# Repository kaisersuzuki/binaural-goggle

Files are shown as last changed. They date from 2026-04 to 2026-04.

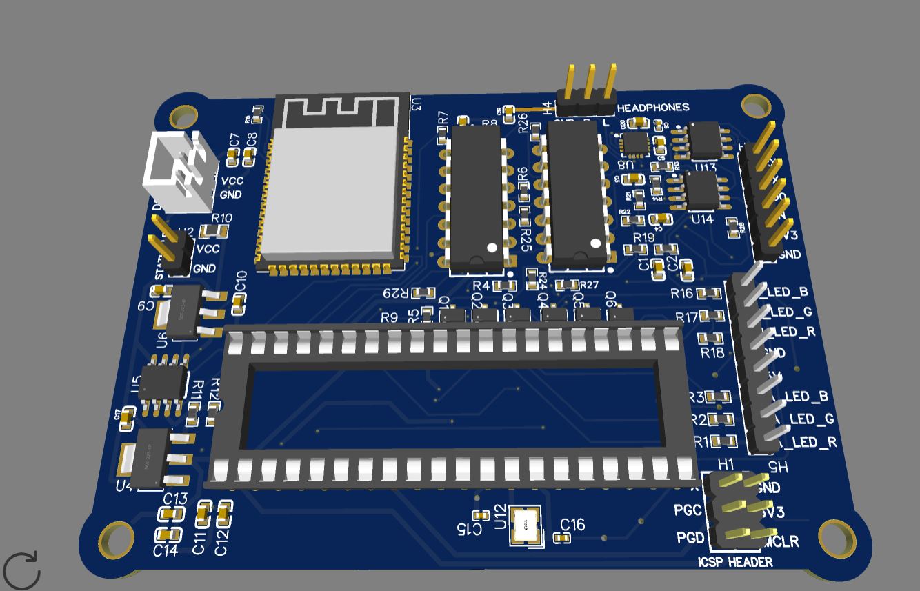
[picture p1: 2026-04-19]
hardware/pcb/images/1.JPG

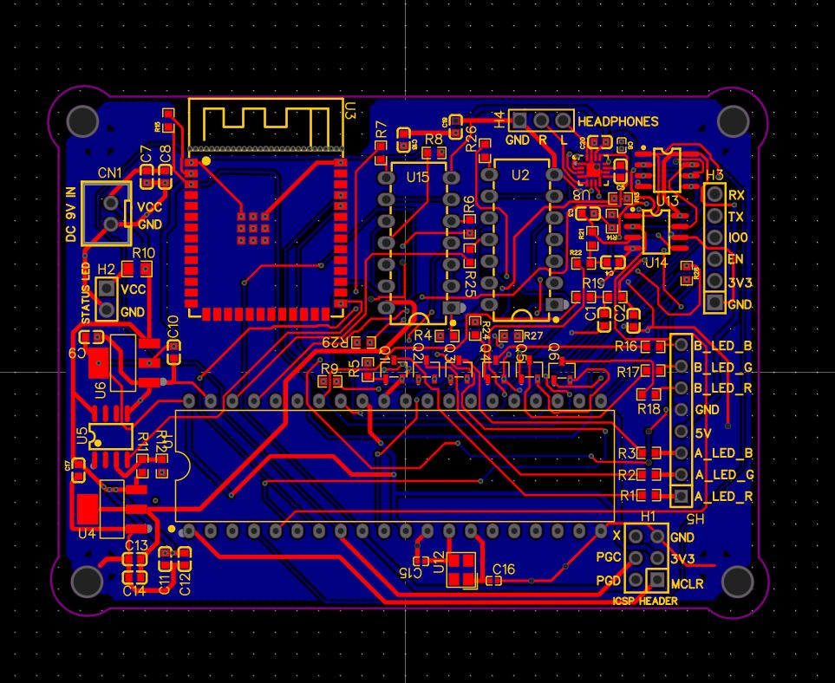
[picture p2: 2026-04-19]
hardware/pcb/images/2.JPG

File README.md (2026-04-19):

# Binaural Beat + RGB LED Goggle Controller

A DIY meditation device combining a dsPIC30F4013 microcontroller with an ESP32-WROOM-32E,
RGB LED arrays mounted in ski goggle frames, binaural beat audio output, and WiFi control
via an embedded ESP32 web server. Housed in a custom ASA FDM 3D-printed enclosure.

**License:** CC BY-NC 4.0 — personal/educational use only, not for commercial use.

---

## Hardware Overview

| Component | Part | Notes |
|---|---|---|
| Microcontroller | dsPIC30F4013-20I/P | PDIP-40, socketed, DigiKey |
| WiFi module | ESP32-WROOM-32E | SMD, JLCPCB assembled |
| Headphone amp | TPA6132A2 | WQFN-17, SMD |
| Digital pot (volume) | AD5220BRZ50 | SOIC-8, SPI, 64-step × 2 |
| 3.3V LDO | LD1117AG-3.3V | SO-8 |
| 5V LDO | AMS1117-5.0 | SOT-223 |
| Battery monitor | MAX8212ESA+T | SOIC-8 |
| LED driver | NTE74HC14 (74HC14) | Schmitt inverter × 2 ICs |
| LED transistor | 2N3904S | NPN × 6 |
| Crystal | 10MHz | HC-49S |
| LEDs | RGB common-cathode | 3× per eye, 2 eyes |
| Enclosure | Custom FDM ASA, JLC3DP | 99×79×51mm body + lid |
| PCB | 2-layer FR4, JLCPCB | 84.4×62.4mm, rounded corners |

### Panel Connectors
| Connector | Part | Location | Function |
|---|---|---|---|
| DC barrel jack | 5.5×2.1mm | Rear panel | 9V power input |
| Power switch | 12mm SPST latching toggle | Rear panel | Power on/off |
| GX16-8 | Female chassis socket | Front panel | Goggle cable |
| Headphone jack | Neutrik NJ3FP6C | Front panel | Stereo TRS output |
| Status LED | 5mm panel mount | Front panel | Power indicator |

---

## PCB Pin Assignments

### dsPIC30F4013 (U1)
| Pin | Function | Connected to |
|-----|---|---|
| 1 | MCLR | 10kΩ → 3.3V, ICSP |
| 6 (RB4) | Eye A — Red | HC14 → 2N3904 → LED |
| 7 (RB5) | Eye A — Green | HC14 → 2N3904 → LED |
| 8 (RB6/PGC) | Eye A — Blue | HC14 → 2N3904 → LED |
| 9 (RB7/PGD) | Eye B — Red | HC14 → 2N3904 → LED |
| 10 (RB8) | Eye B — Green | HC14 → 2N3904 → LED |
| 38 (RB9) | Eye B — Blue | HC14 → 2N3904 → LED |
| 37 (RB10) | TPA6132A2 EN | Amp enable (HIGH = on) |
| 4 (RB2) | AD5220 /CS | SPI chip select |
| 5 (RB3) | AD5220 U/D | SPI up/down |
| 24 (RF6/SCK1) | AD5220 CLK | SPI clock |
| 25 (RF3/SDO1) | AD5220 DI | SPI data |
| 27 (RF5/U2TX) | ESP32 RX | UART2 TX |
| 28 (RF4/U2RX) | ESP32 TX | UART2 RX |
| 33 (RD1/OC2) | PWM Right | Audio PWM right channel |
| 34 (RD0/OC1) | PWM Left | Audio PWM left channel |
| 13 (OSC1) | Crystal | 10MHz |
| 14 (OSC2) | Crystal | 10MHz |

> **Note:** RB6 and RB7 are shared with PGC/PGD (ICSP programming pins).
> LEDs will flash briefly during firmware programming — this is expected and harmless.

### ESP32-WROOM-32E (U7)
| GPIO | Function | Connected to |
|---|---|---|
| GPIO16 (RX2) | UART2 RX | dsPIC U2TX (RF5) |
| GPIO17 (TX2) | UART2 TX | dsPIC U2RX (RF4) |
| GPIO0 | Boot mode | Voltage divider on PCB |

### Connector Headers
| Ref | Pins | Function |
|-----|---|---|
| J1 / H1 | 2×3 (6-pin) | ICSP — dsPIC programming (PICkit 4) |
| J2 / H3 | 1×6 | ESP32 programming (GND/3V3/EN/IO0/TX0/RX0) |
| J3 / PS1 | GX16-8 | Goggle cable (A_R/A_G/A_B/B_R/B_G/B_B/5V/GND) |
| J4 / H4 | 1×3 | Headphone jack (GND/R/L → Neutrik NJ3FP6C) |
| J5 / H2 | 1×2 | Status LED (VCC/GND) |
| J6 / CN1 | 1×2 | 9V power input (VCC/GND from barrel jack) |
| J7 | — | UART debug (not populated) |

### GX16-8 Pin Map
| GX16-8 Pin | Signal |
|---|---|
| 1 | Eye A — Red |
| 2 | Eye A — Green |
| 3 | Eye A — Blue |
| 4 | Eye B — Red |
| 5 | Eye B — Green |
| 6 | Eye B — Blue |
| 7 | +5V |
| 8 | GND |

---

## Repository Structure

```
binaural-goggle/
├── firmware/
│   ├── dspic/
│   │   └── src/
│   │       └── dspic_firmware.c      # dsPIC30F4013 main firmware
│   └── esp32/
│       └── src/
│           └── main.cpp              # ESP32 WiFi + web server firmware
├── hardware/
│   ├── schematic/
│   │   ├── binaural_goggle_schematic.html     # Schematic rev 0.1 (original)
│   │   ├── Schematic_AUDIO-CONTROLLER_REV1.1.pdf  # Final schematic
│   │   └── images/
│   │       ├── schematic_rev0.1.png
│   │       └── schematic_rev1.1_*.png
│   ├── pcb/
│   │   ├── Gerber_AUDIO-CONTROLLER_2026-04-19.zip
│   │   ├── PCB_AUDIO-CONTROLLER_2026-04-19.json
│   │   ├── SCH_AUDIO-CONTROLLER_2026-04-19.json
│   │   └── images/
│   │       ├── pcb_top.jpg
│   │       ├── pcb_bottom.jpg
│   │       └── pcb_3d_*.jpg
│   └── bom/
│       └── BOM_AUDIO-CONTROLLER.csv
├── enclosure/
│   ├── enclosure_body_v8_FINAL.stl
│   ├── enclosure_lid_v8_FINAL.stl
│   └── insert_drawing_v7.pdf
└── docs/
    ├── README.md                     # This file
    ├── ARCHITECTURE.md
    ├── UART_PROTOCOL.md
    └── PROGRAMMING.md
```

---

## Firmware: dsPIC30F4013

### Build Environment
- MPLAB X IDE (latest)
- XC16 compiler
- PICkit 4 programmer

### Key Parameters
| Parameter | Value |
|---|---|
| Crystal | 10MHz |
| PLL | ×4 |
| Fcy | 20MHz |
| DDS sample rate | 8kHz (Timer1 ISR) |
| PWM frequency | ~256kHz (OC1/OC2) |
| UART2 baud rate | 9600 |
| Beat range | 0.5–40Hz |
| Carrier range | 50–500Hz |
| Volume steps | 0–63 (AD5220) |

### Beat Pattern (default)
| Phase | Frequency | Duration |
|---|---|---|
| Baseline | 4Hz (theta) | continuous |
| Spike | 8Hz | 40 seconds every ~8 min |
| Dip | 2Hz | 90 seconds every ~13 min |
| Ramp | smooth | 3 second transitions |

### UART Command Protocol
Commands are ASCII, newline-terminated, sent from ESP32 to dsPIC:

```
BEAT:<hz>           — set beat frequency (0.5–40.0)
CARRIER:<hz>        — set carrier frequency (50.0–500.0)
VOL:<0-63>          — set volume step
RGB_A:<r>,<g>,<b>   — set eye A color (0–255 each)
RGB_B:<r>,<g>,<b>   — set eye B color
RGB_AB:<r>,<g>,<b>  — set both eyes same color
STATUS              — returns current state string
RESET               — reset sequencer to baseline 4Hz
```

dsPIC responds with `OK:<cmd>` or `ERR:UNKNOWN`.

---

## Firmware: ESP32

### Build Environment
- VS Code + PlatformIO
- Arduino framework for ESP32

### WiFi
| Setting | Value |
|---|---|
| Mode | AP (Access Point) |
| SSID | BinauralGoggle |
| Password | meditate123 |
| Web UI | http://192.168.4.1 |
| OTA hostname | binaural-goggle |
| OTA password | goggle-ota |

### First Flash (via J2 programming header)
1. Connect FTDI/CP2102 adapter to J2 (GND/3V3/EN/IO0/TX0/RX0)
2. Hold IO0 low during power-up to enter boot mode
3. Flash via PlatformIO: `pio run --target upload`
4. Subsequent updates via OTA

### Production Flash Note
Once `Serial` (USB debug) is no longer needed, the firmware uses `Serial2` only
(GPIO16/17) for dsPIC communication. USB serial is kept for debug output.

---

## Power

- Input: 9V DC wall adapter, 5.5×2.1mm center-positive, 1A minimum
- Panel switch (rear): SPST latching 12mm toggle, in series with 9V input
- 3.3V rail: LD1117AG-3.3V LDO (logic, dsPIC, ESP32)
- 5V rail: AMS1117-5.0 LDO (LEDs, headphone amp)
- No battery, no protection diode required

---

## Programming the dsPIC

Connect PICkit 4 to J1 (ICSP header, 2×3 male):

| Pin | Signal |
|-----|---|
| 1 | MCLR |
| 2 | VDD (3.3V) |
| 3 | VSS (GND) |
| 4 | PGD (RB7) |
| 5 | PGC (RB6) |
| 6 | NC |

> LEDs may flash briefly during programming due to PGC/PGD sharing RB6/RB7.

---

## 3D-Printed Enclosure

Printed by JLC3DP in ASA black FDM.

| Part | File | Dimensions |
|---|---|---|
| Body | enclosure_body_v8_FINAL.stl | 99×79×39.5mm |
| Lid | enclosure_lid_v8_FINAL.stl | 99×79×11.5mm |
| Insert drawing | insert_drawing_v7.pdf | 4× M3×4×5 at (±38, ±27mm) |

### Panel Hole Positions (Z=24mm from bottom)
| Hole | Diameter | X position | Panel |
|---|---|---|---|
| GX16-8 | 16.2mm | X=−20 | Front |
| TRS headphone | 9.5mm | X=+22 | Front |
| Status LED | 5.2mm | X=0 | Front |
| DC barrel jack | 8.2mm | X=+20 | Rear |
| Power switch | 12.2mm | X=−20 | Rear |

---

## Hardware Still Needed (to order)

- [ ] Neutrik NJ3FP6C — 1/4" stereo TRS panel jack
- [ ] GX16-8 female chassis socket + male cable plug
- [ ] 12mm SPST latching toggle switch
- [ ] 5.5×2.1mm DC barrel jack (panel mount)
- [ ] 9V DC wall adapter, 1A, center-positive
- [ ] PICkit 4 programmer
- [ ] dsPIC30F4013-20I/P (PDIP-40, DigiKey)
- [ ] USB-UART adapter (FTDI or CP2102) for initial ESP32 flash

---

*Brad Beidler · 2026 · CC BY-NC 4.0*

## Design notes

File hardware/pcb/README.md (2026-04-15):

# PCB Files

> **Status:** Layout in progress with JLCPCB Layout Service (Atan). Gerbers will be added here once received and approved.

## What goes here

Once the PCB design is finalized, this folder should contain:

| Folder | Contents |
|---|---|
| `gerbers/` | Production Gerber files (RS-274X) — what JLCPCB needs to manufacture |
| `bom/` | Bill of materials (CSV with LCSC part numbers for each component) |
| `cpl/` | Component Placement List (CSV with X/Y/rotation for pick-and-place) |

Plus the EasyEDA Pro source files:

- `binaural_goggle.epro` — EasyEDA Pro project file
- `schematic.json` — schematic source
- `pcb.json` — PCB layout source

## Specs

- 82 × 60 mm
- 2-layer, 1.6mm thick, 1oz copper
- ENIG finish (or HASL for cheaper)
- 4× M3 mounting holes at corners (3.5mm clearance, non-plated)
- Top side components only

## Key components

- **U1** dsPIC30F4013 — PDIP-40, socketed (DIP socket on PCB, chip inserted by user, not assembled by JLCPCB)
- **U2** ESP32-WROOM-32E — SMD module, JLCPCB assembled
- **U3** TPA6132A2 (or NTE941M) — headphone amp
- **U4** AD5220 — SPI digital pot
- **U5/U6** MAX603 ×2 — 3.3V and 5V LDOs
- **U7/U8** NTE74HC14 ×2 — Schmitt inverters for LED drivers
- 6× 2N3904 — RGB LED drivers
- All passives 0603 SMD

## Programming headers

Two headers must be exposed on the board:

1. **J1 — dsPIC ICSP**: 2×3 pin, 2.54mm. Pinout: MCLR / VDD / VSS / PGD / PGC / NC
2. **JESP — ESP32 programming**: 1×6 pin, 2.54mm. Pinout: GND / 3V3 / EN / IO0 / TX0 / RX0
   Plus BOOT and RESET momentary pushbuttons (or auto-reset transistor pair)

See `docs/programming.md` for use.

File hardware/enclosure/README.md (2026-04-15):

# Enclosure

3D-printed ASA case for the controller PCB. Currently at **v7** — pressure-fit lid, no lid screws.

## Files

| File | Purpose |
|---|---|
| `stl/enclosure_body_v7.stl` | Main body — 99 × 79 × 39.5 mm, open top, internal PCB standoffs |
| `stl/enclosure_lid_v7.stl` | Press-fit lid — 99 × 79 × 11.5 mm |
| `drawings/insert_drawing_v7.pdf` | Heat-set insert location drawing for JLC3DP order |

## Specs

- Material: **ASA**, black
- Process: **FDM** (JLC3DP)
- Surface finish: **yes** (smoother outer face)
- Threaded inserts: **4× M3 × 4mm OD × 5mm long**, all in PCB standoffs at (±38, ±27)
- Lid: pressure-fit, no inserts, no screws
- Mounting: PCB attaches to body via 4× M3 cap-head screws into the heat-set inserts

## Ordering from JLC3DP

1. Upload `enclosure_body_v7.stl` and `enclosure_lid_v7.stl`
2. For the body only, select:
   - Material: ASA
   - Color: Black
   - Surface finish: Yes
   - Threaded insert: M3 × 4 × 5, **quantity 4**
   - Upload `insert_drawing_v7.pdf` for insert locations
3. For the lid: same material/color/finish, no inserts

Cost: ~$25–35 per set. Lead time ~5–7 business days.

## SCAD source (TODO)

The `scad/` folder is a placeholder. Brad has the working SCAD source locally — drop `enclosure_v7.scad` here when convenient so the parametric source lives in version control alongside the STLs.

## History

- **v1–v6**: iterations during early development (not in repo)
- **v7** (current): pressure-fit redesign, removed all 4 lid bosses, 4 PCB inserts only

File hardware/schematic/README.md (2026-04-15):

# Schematic

| File | Description |
|---|---|
| `binaural_goggle_schematic_rev01.html` | Rev 0.1 — single-color red LEDs, no ESP32 |
| `binaural_goggle_schematic_rev02.png` | Rev 0.2 — adds ESP32, RGB LEDs, UART link, PDIP-40 dsPIC |

The HTML version is interactive (open in any browser). The PNG is the current revision and what's being implemented.

## Source files (TODO)

The EasyEDA Pro project source (`.epro`, `.json`) belongs in `../pcb/` and will be added once the layout service finalizes the design.

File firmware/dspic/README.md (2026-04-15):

# dsPIC30F4013 Firmware

The audio + LED engine. Generates binaural beats via DDS, drives RGB LEDs via soft-PWM, takes commands from the ESP32 over UART1.

## Toolchain

- **MPLAB X IDE** (free from microchip.com)
- **XC16 compiler** v2.x or later (free)
- **PICkit 4** programmer (~$50, DigiKey)

## Building

1. Open MPLAB X IDE → **File → New Project → Microchip Embedded → Standalone Project**
2. Family: **16-bit DSCs (dsPIC30)**, Device: **dsPIC30F4013**
3. Tool: **PICkit 4**, Compiler: **XC16**
4. Project name: `binaural_goggle_dspic`
5. Right-click *Source Files* → Add Existing Item → select `src/dspic_firmware.c`
6. **Build** (hammer icon)

## Flashing

1. Connect PICkit 4 to your Mac via USB
2. Connect PICkit 4 cable to PCB **J1** (5-pin ICSP header)
3. Pin orientation on J1: MCLR / VDD / VSS / PGD / PGC (pin 1 marked)
4. In MPLAB X click the **Make and Program Device** icon (downward arrow)
5. Watch the output pane — should see "Programming complete"

## Configuration

Edit constants near the top of `dspic_firmware.c`:

```c
#define SAMPLE_RATE         8000U     // DDS interrupt rate
#define DEFAULT_CARRIER_HZ  128       // Initial carrier
#define DEFAULT_BEAT_HZ     4.0f      // Initial beat
```

The runtime command interface (over UART1 from the ESP32) lets you change these without reflashing — see [`docs/uart_protocol.md`](../../docs/uart_protocol.md).

## Pin map

See header comment block in `src/dspic_firmware.c` for the full pin assignments. Summary:

| Pin | Function |
|---|---|
| RD0 (OC1) | Left audio PWM |
| RD1 (OC2) | Right audio PWM |
| RF6/RF7 + RB2/RB3 | SPI to AD5220 volume pot |
| RF2/RF3 | UART1 to ESP32 |
| RG2/3/4 | Left eye R/G/B LEDs |
| RG6/7/8 | Right eye R/G/B LEDs |
| AN0 | Battery voltage divider |

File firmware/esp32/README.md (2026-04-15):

# ESP32 Firmware

WiFi controller and web UI host. Receives commands from a browser over WiFi, translates them to UART ASCII commands for the dsPIC.

> **Status:** Smoke-test foundation only. Verified working end-to-end on ESP32 DevKitC (April 2026). Production version will add full command set, OTA updates, SPIFFS-served UI, and STA mode fallback.

## Toolchain

- **VS Code** with the **PlatformIO IDE** extension
- **CH340 USB-UART driver** (Mac): `brew install --cask wch-ch34x-usb-serial-driver`

## Building & flashing (during development)

1. Open this folder (`firmware/esp32/`) in VS Code with PlatformIO installed
2. Plug in the ESP32 DevKitC via USB
3. Click the **→** (Upload) icon in the bottom blue status bar
4. Click the **🔌** (Serial Monitor) icon to watch logs

## Flashing the final PCB (one-time)

The production PCB exposes a 6-pin programming header with `GND / 3V3 / EN / IO0 / TX0 / RX0`. To flash the initial firmware:

1. Connect a USB-UART adapter (FTDI or CP2102) to the header
2. Hold BOOT, tap RESET, release BOOT to enter download mode
3. `pio run --target upload` (or use the upload arrow in VS Code)
4. After this first flash, all subsequent updates happen via WiFi (OTA) — see below

## Using the web UI

1. After flashing, the ESP32 creates a WiFi network: **BinauralGoggle** (password: `meditate123`)
2. Connect from any phone/laptop
3. Browse to `http://192.168.4.1`
4. Adjust sliders, hit APPLY
5. Watch the serial monitor — you'll see the UART command that would be sent to the dsPIC

## Architecture

```
[Browser] ─HTTP─→ [ESP32 web server] ─UART2─→ [dsPIC30F4013]
              ←─events─                ←──────
```

- **Web server:** ESPAsyncWebServer on port 80
- **UI:** Single-page HTML/CSS/JS (currently inline, will move to SPIFFS)
- **UART bridge:** Translates JSON/form params to ASCII commands per [UART protocol](../../docs/uart_protocol.md)
- **OTA:** ArduinoOTA library, firmware updates via WiFi after initial flash

## Pin map (final PCB)

| ESP32 GPIO | Function |
|---|---|
| 1 (TX0)  | Programming header — initial flash only |
| 3 (RX0)  | Programming header — initial flash only |
| 16 (RX2) | UART2 from dsPIC TX (RF3) |
| 17 (TX2) | UART2 to dsPIC RX (RF2) |
| EN | Reset (boot button) |
| 0 | Boot mode select (boot button) |

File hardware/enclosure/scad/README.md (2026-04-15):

# OpenSCAD Source

Place `enclosure_v7.scad` here when ready.

The STL files in `../stl/` were exported from this source. Keeping the SCAD here in version control means future revisions can be parametric edits rather than starting from scratch.

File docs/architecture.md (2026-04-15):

# System Architecture

## Block diagram

```
┌─────────────────────────────────────────────────────────────────────┐
│                      BINAURAL GOGGLE CONTROLLER                     │
└─────────────────────────────────────────────────────────────────────┘

        9V battery
            │
        ┌───┴────┐
        │ MAX603 │── 3.3V ──┬─→ dsPIC VDD/AVDD
        │  LDO   │          ├─→ ESP32 3V3
        └────────┘          └─→ AD5220 / HC14 logic
            │
        ┌───┴────┐
        │ MAX603 │── 5.0V ──┬─→ NTE941M op-amp VCC
        │ (SET)  │          └─→ RGB LED supply
        └────────┘

  ┌─────────────────┐   WiFi    ┌──────────────────┐
  │  Phone/Laptop   │◄─────────►│  ESP32-WROOM-32E │
  │  (web browser)  │           │  (web server)    │
  └─────────────────┘           └────────┬─────────┘
                                         │ UART2 @ 115200
                                         │
                                ┌────────▼─────────┐
                                │  dsPIC30F4013    │
                                │  (PDIP-40)       │
                                │                  │
                                │  • DDS @ 8kHz    │
                                │  • Beat seq      │
                                │  • Noise gen     │
                                │  • SoftPWM LEDs  │
                                └──┬──────┬───┬────┘
                                   │      │   │
            ┌──── PWM ─────────────┘      │   └─── 6× GPIO ───┐
            │                             │                    │
            ▼                             ▼                    ▼
   ┌─────────────────┐         ┌─────────────────┐    ┌──────────────┐
   │  RC LPF (×2)    │         │  AD5220 SPI pot │    │  HC14 + 2N3904│
   │  Fc≈1.6kHz      │         │  (master vol)   │    │  RGB drivers  │
   └────────┬────────┘         └────────┬────────┘    └──────┬───────┘
            │                           │                    │
            ▼                           │                    ▼
   ┌─────────────────┐                  │           ┌──────────────┐
   │  NTE941M unity  │◄─────────────────┘           │  RGB LEDs    │
   │  buffers (×2)   │                              │  (in goggles)│
   └────────┬────────┘                              └──────────────┘
            │
            ▼
   ┌─────────────────┐
   │  3.5mm jack     │
   │  → headphones   │
   └─────────────────┘
```

## Why two MCUs

The dsPIC handles all hard-real-time work — running a DDS oscillator at 8 kHz with sample-accurate phase, generating noise, and managing LED PWM all from interrupts. Adding WiFi to that chip would either require a heavier processor or constant priority juggling.

The ESP32 handles only soft-real-time work: receive a web request, parse it, send an ASCII line over UART. It can take its time without affecting audio quality.

This separation also means the audio engine keeps running cleanly even if WiFi drops, the user's phone disconnects, or the ESP32 is OTA-updating itself.

## Programming workflow

| Component | First flash | Updates |
|---|---|---|
| dsPIC30F4013 | PICkit 4 + MPLAB X via J1 ICSP header | PICkit 4 (rare — firmware is stable) |
| ESP32-WROOM-32E | USB-UART adapter via 6-pin programming header | OTA over WiFi via web UI |

## Power

- **9V battery** (or DC jack) → switch → MAX603 ×2 → 3.3V and 5V rails
- **MAX8212** monitors battery voltage and signals dsPIC AN0 when low
- All bypass caps per datasheet

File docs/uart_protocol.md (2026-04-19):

# UART Protocol — ESP32 ↔ dsPIC30F4013

## Physical Layer

| Parameter | Value |
|---|---|
| Baud rate | 9600 |
| Format | 8N1 |
| ESP32 pin (TX) | GPIO17 (Serial2 TX) |
| ESP32 pin (RX) | GPIO16 (Serial2 RX) |
| dsPIC pin (RX) | RF4 / U2RX |
| dsPIC pin (TX) | RF5 / U2TX |
| Logic level | 3.3V (both devices) |

## Message Format

All messages are ASCII, newline (`\n`) terminated.
ESP32 sends commands; dsPIC responds.

## Commands (ESP32 → dsPIC)

| Command | Example | Description |
|---|---|---|
| `BEAT:<hz>` | `BEAT:4.0` | Set beat frequency (0.5–40.0 Hz) |
| `CARRIER:<hz>` | `CARRIER:200.0` | Set carrier frequency (50.0–500.0 Hz) |
| `VOL:<0-63>` | `VOL:32` | Set volume (AD5220 step position) |
| `RGB_A:<r>,<g>,<b>` | `RGB_A:255,0,0` | Set eye A color (0–255 each channel) |
| `RGB_B:<r>,<g>,<b>` | `RGB_B:0,0,255` | Set eye B color |
| `RGB_AB:<r>,<g>,<b>` | `RGB_AB:128,0,128` | Set both eyes same color |
| `STATUS` | `STATUS` | Request current state |
| `RESET` | `RESET` | Reset sequencer to 4Hz baseline |

## Responses (dsPIC → ESP32)

| Response | Meaning |
|---|---|
| `OK:BEAT` | Beat frequency accepted |
| `OK:CARRIER` | Carrier frequency accepted |
| `OK:VOL` | Volume set |
| `OK:RGB_A` | Eye A color set |
| `OK:RGB_B` | Eye B color set |
| `OK:RGB_AB` | Both eyes set |
| `OK:RESET` | Sequencer reset |
| `BEAT:x.x CARRIER:x.x VOL:xx` | Status response |
| `ERR:UNKNOWN` | Unrecognized command |
| `READY:BINAURAL_GOGGLE_V2` | Boot message (sent once on power-up) |

## Timing Notes

- dsPIC responds within ~1ms for most commands
- Volume changes (`VOL:`) take longer if stepping many positions (64 steps max = ~5ms)
- ESP32 waits up to 200ms for a response before returning "timeout" to the web UI
- STATUS response is always sent within 5ms

## Beat Frequency Ranges

| Range | Brainwave | Effect |
|---|---|---|
| 0.5–4 Hz | Delta | Deep sleep |
| 4–8 Hz | Theta | Meditation, drowsiness |
| 8–14 Hz | Alpha | Relaxed focus |
| 14–30 Hz | Beta | Active thinking |

Default session pattern:
- **4Hz theta** baseline
- **8Hz spike** every ~8 minutes (40 second duration)
- **2Hz dip** every ~13 minutes (90 second duration)
- All transitions ramp over 3 seconds

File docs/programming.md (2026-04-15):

# Programming Guide

How to flash firmware on both MCUs.

## Required tools

- **PICkit 4** programmer for the dsPIC (~$50 from DigiKey/Microchip)
- **MPLAB X IDE** + **XC16 compiler** for dsPIC firmware (free)
- **VS Code** + **PlatformIO** for ESP32 firmware (free)
- **CH340/CP2102 USB-UART adapter** for initial ESP32 flash (~$5)
- **CH340 driver** (Mac): `brew install --cask wch-ch34x-usb-serial-driver`

## Order of operations

1. Insert the dsPIC30F4013 into its PDIP-40 DIP socket on the assembled PCB
2. Flash the dsPIC via the J1 ICSP header
3. Flash the ESP32 via the 6-pin programming header
4. From here on, ESP32 firmware updates happen over WiFi (OTA)

## Flashing the dsPIC

1. Open `firmware/dspic/src/dspic_firmware.c` in MPLAB X (create a new project targeting **dsPIC30F4013** with **XC16** compiler)
2. Connect PICkit 4 → Mac via USB
3. Connect PICkit 4 → PCB **J1** (5-pin ICSP header). Pin 1 is marked on the board
4. Hit **Make and Program Device** (downward arrow icon)
5. Watch the output pane for "Programming complete"

If you get a "device not detected" error, check the J1 connector orientation and that the dsPIC has both VDD (3.3V) and VSS (GND) connected.

## Flashing the ESP32 (initial)

1. Connect USB-UART adapter to the 6-pin programming header on the PCB:
   - Adapter GND  → Header GND
   - Adapter 3V3  → Header 3V3 (or leave disconnected if board is powered via main supply)
   - Adapter TX   → Header RX0
   - Adapter RX   → Header TX0
   - Adapter DTR  → Header EN  (optional, for auto-reset)
   - Adapter RTS  → Header IO0 (optional, for auto-boot)
2. Hold **BOOT** button on PCB, tap **RESET**, release **BOOT**
3. In `firmware/esp32/`: `pio run --target upload`
4. After upload, tap **RESET** to start running

## Flashing the ESP32 (OTA, after first flash)

1. Connect to the WiFi network the ESP32 is on (either AP mode or your home network)
2. In your browser, go to the device's address (default: `http://192.168.4.1/update`)
3. Upload the new `firmware.bin` (built by `pio run`)
4. Device reboots automatically when complete

OTA is the normal update path — you should rarely need the wired programming header after the initial flash.

## Troubleshooting

| Symptom | Likely cause |
|---|---|
| PICkit 4 not detected | USB cable issue, or PICkit 4 needs a firmware update via MPLAB X |
| `device ID mismatch` | Wrong device selected in MPLAB X project — must be exactly dsPIC30F4013 |
| ESP32 upload "Connecting..." hangs | BOOT/RESET sequence wrong, or auto-reset wiring missing |
| Garbled serial output | Baud rate mismatch — check both ends are 115200 |
| WiFi network doesn't appear | Check `WiFi.softAP()` succeeded in serial logs |
| OTA upload fails | Check device IP, ensure same network, firewall blocking port 3232 |

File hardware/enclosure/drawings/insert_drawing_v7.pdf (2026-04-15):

## BINAURAL GOGGLE CONTROLLER — ENCLOSURE BODY v7

Heat-Set Insert Locations | M3 x 4mm OD x 5mm long | 4 inserts total
Brad Beidler | 2026 | JLC3DP ASA Black FDM | Pressure-fit lid (no lid inserts)

### TOP VIEW (looking down into open top of body)

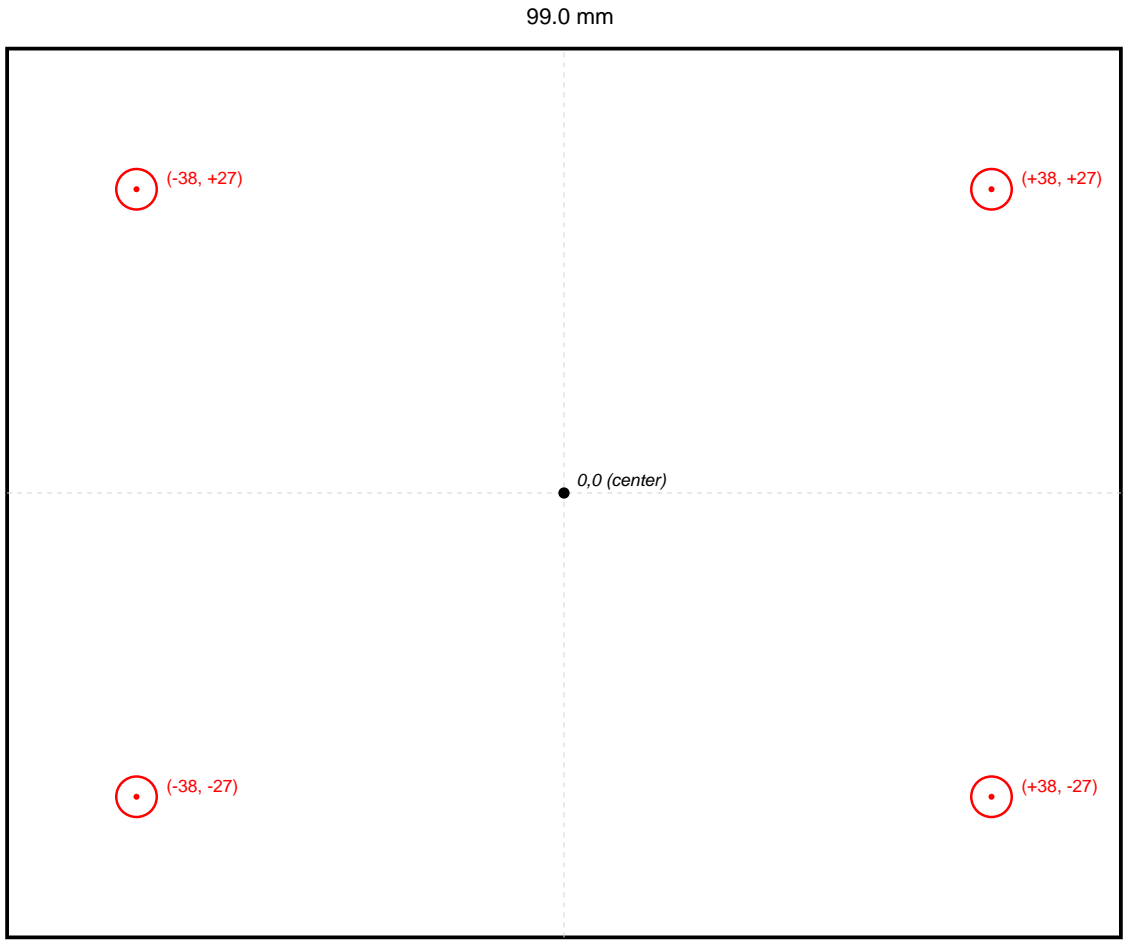
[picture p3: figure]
(+38, +27) 0,0 (center)

79.0 mm

LEGEND:
PCB standoff inserts (4 total) — at (±38, ±27)mm — short interior columns, hole faces UP

INSERT SPECIFICATION:

Insert type: | Brass heat-set, M3 x 4mm OD x 5mm long
JLC3DP catalog spec: | M3 x 4 x 5
Hole diameter: | 3.6 mm
Hole depth: | 7.0 mm
Total quantity: | 4 inserts
Orientation: | All 4 holes open to TOP face of body

NOTES:

1. All 4 insert holes open to the TOP face of the enclosure body (open side facing up).
2. PCB standoffs are short interior columns (~10mm tall) — accept inserts for M3 screws holding the PCB.
3. Lid is PRESSURE-FIT — no screws, no lid bosses, no lid inserts required.
4. Body external dimensions: 99 x 79 x 39.5 mm. Lid: 99 x 79 x 11.5 mm.
5. Material: ASA, black, FDM. Surface finish: yes.
File: enclosure_body_v7.stl | Drawing rev: v7-INS-01 | For JLC3DP threaded insert installation | Page 1 of 1

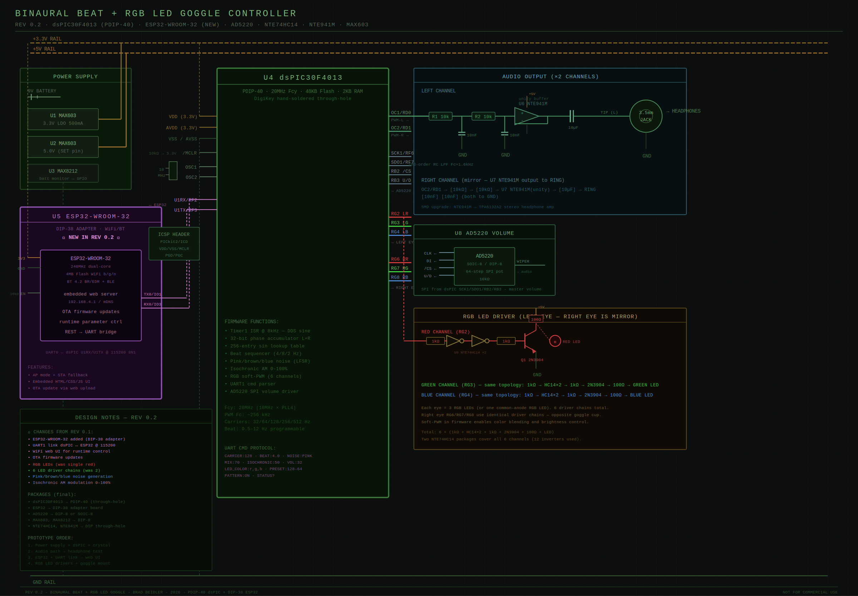
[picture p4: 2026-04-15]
hardware/schematic/binaural_goggle_schematic_rev02.png

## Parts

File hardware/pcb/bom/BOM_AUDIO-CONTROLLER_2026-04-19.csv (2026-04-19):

ID | Name | Designator | Footprint | Quantity | Manufacturer Part | Manufacturer | Supplier | Supplier Part | Price
1 | GX16-8 | H5 | HDR-TH_8P-P2.54-V-M | 1 | B-2100S08P-A110 | Ckmtw(灿科盟) | LCSC | C124381 | 0.08
2 | 10kΩ | R15,R13,R14,R19,R20,R21,R22 | R0603 | 7 | 0603WAF1002T5E | UNI-ROYAL(厚声) | LCSC | C25804 | 0.001
3 | ESP32-S3-WROOM-1(N8R8) | U3 | WIRELM-SMD_ESP32-S3-WROOM-1 | 1 | ESP32-S3-WROOM-1-N8R8 | ESPRESSIF(乐鑫) | LCSC | C2913201 | 5.043
4 | DC IN | CN1 | CONN-TH_2P-P2.50-XH2.54-2P | 1 | SH-XH2.54-2P | 深海电子 | LCSC | C53261323 | 0.004
5 | 10nF | C1,C2,C3,C4 | C0603 | 4 | 0603B103K500NT | FH(风华) | LCSC | C57112 | 0.003
6 | 1uF | C5 | C0603 | 1 | CGA3E1X7R1V105KT000S | TDK | LCSC | C36828386 | 0.091
7 | 100nF | C7,C10,C11,C14,C17,C18,C19,C20 | C0603 | 8 | CC0603KRX7R9BB104 | YAGEO(国巨) | LCSC | C14663 | 0.003
8 | 10uF | C8,C9,C12,C13 | C0603 | 4 | CL10A106KP8NNNC | SAMSUNG(三星) | LCSC | C19702 | 0.008
9 | 2.2uF | C6 | C0402 | 1 | GRM155D71C225ME11D | muRata(村田) | LCSC | C668350 | 0.07
10 | 22pF | C15,C16 | C0402 | 2 | CQ0402JRNPO9BN220 | YAGEO(国巨) | LCSC | C577409 | 0.008
11 | ICSP HEADER | H1 | HDR-TH_6P-P2.54-V-F-R2-C3-S2.54 | 1 | Female header/2.54mm2x3 Female header | ReliaPro | LCSC | C47552
12 | STATUS LED | H2 | HDR-TH_2P-P2.54-V-M-1 | 1 | 826629-2 | TE Connectivity(泰科电子) | LCSC | C86471 | 0.415
13 | ESP32 | H3 | HDR-TH_6P-P2.54-V-M-1 | 1 | 2.54-1x6P直针 | BOOMELE(博穆精密) | LCSC | C37208 | 0.042
14 | NJ3FP6C | H4 | HDR-TH_3P-P2.54-V-M-1 | 1 | 2.54-1*3P针 | BOOMELE(博穆精密) | LCSC | C49257 | 0.021
15 | 2N3904S-HXY | Q1,Q2,Q3,Q4,Q5,Q6 | SOT-23-3_L3.0-W1.7-P0.95-LS2.9-BR | 6 | 2N3904S-HXY | HXY MOSFET(华轩阳电子) | LCSC | C46682376 | 0.01
16 | 100R | R1,R2,R3,R16,R17,R18 | R0603 | 6 | 0603WAF1204T5E (SMT业务专用) | null | LCSC | C22766
17 | 1kΩ | R4,R5,R6,R7,R8,R9,R24,R25,R26,R27,R28,R29 | R0603 | 12 | 0603WAF1001T5E | UNI-ROYAL(厚声) | LCSC | C21190 | 0.002
18 | 100kΩ | R11 | R0603 | 1 | 0603WAF1003T5E | UNI-ROYAL(厚声) | LCSC | C25803 | 0.002
19 | 33kΩ | R12 | R0603 | 1 | 0603WAD3302T5E | UNI-ROYAL(厚声) | LCSC | C407593 | 0.005
20 | 1.2kΩ | R10 | R0805 | 1 | FRC0805F1201TS | FOJAN(富捷) | LCSC | C2933293 | 0.002
21 | DSPIC30F4013-20E/P | U1 | PDIP-40_DSPIC30F3014-30IP | 1 | dsPIC30F4013-20E/P | MICROCHIP(美国微芯) | LCSC | C613576 | 18.781
22 | 74HC14 | U2,U15 | DIP-14_L19.1-W6.4-P2.54-LS7.6-BL | 2 | 74HC14 | I-CORE(中微爱芯) | LCSC | C2974582 | 0.193
23 | AMS1117-5.0 | U4 | SOT-223_L6.5-W3.5-P2.30-LS7.0-BR | 1 | AMS1117-5.0 | AMS | LCSC | C6187 | 0.231
24 | MAX8212ESA+T | U5 | SOIC-8_L5.0-W4.0-P1.27-LS6.1-BL | 1 | MAX8212ESA+T | ADI(亚德诺)/MAXIM(美信) | LCSC | C2070193 | 5.251
25 | LD1117AG-3.3V-A | U6 | SOT-223-3_L6.5-W3.4-P2.30-LS7.0-BR | 1 | LD1117AG-3.3V-A | UTC(友顺) | LCSC | C474404 | 0.075
26 | TPA6132A2RTER | U8 | WQFN-16_L3.0-W3.0-P0.50-TL-EP1.6 | 1 | TPA6132A2RTER | TI(德州仪器) | LCSC | C69901 | 1.269
27 | 10MHz | U12 | CRYSTAL-SMD_4P-L3.2-W2.5-BL | 1 | XC32M4-10.000-F10LLDT | HCI(杭晶) | LCSC | C2848219 | 0.149
28 | AD5220BRZ50 | U13,U14 | SOIC-8_L4.9-W3.9-P1.27-LS6.2-BL | 2 | AD5220BRZ50 | ADI(亚德诺) | LCSC | C649362 | 5.701

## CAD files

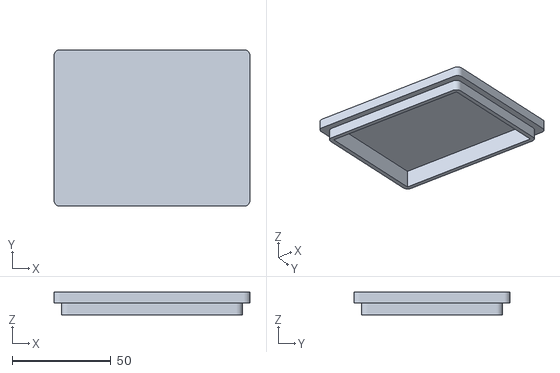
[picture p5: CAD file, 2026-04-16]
hardware/enclosure/stl/enclosure_lid_v8_FINAL.stl
99.0 x 79.0 x 11.5

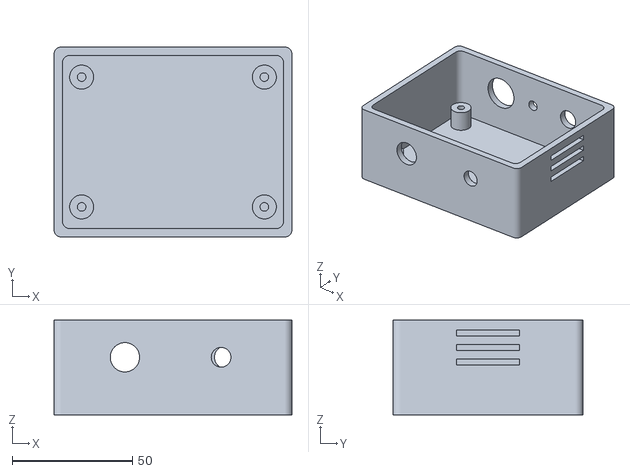
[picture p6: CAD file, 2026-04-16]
hardware/enclosure/stl/enclosure_body_v8_FINAL.stl
99.0 x 79.0 x 39.5

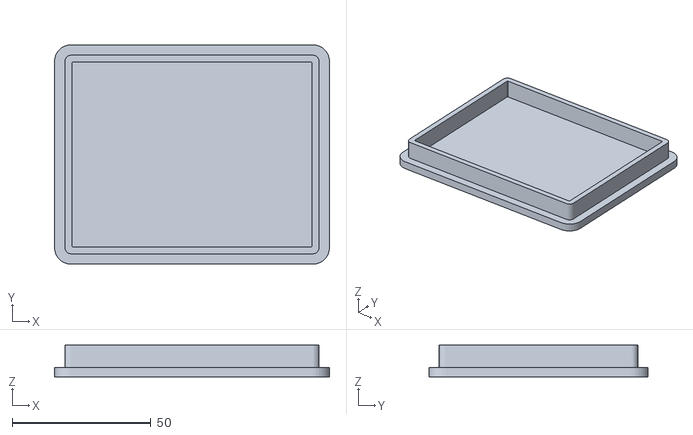
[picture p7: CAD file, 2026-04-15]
hardware/enclosure/stl/enclosure_lid_v7.stl
99.0 x 79.0 x 11.5

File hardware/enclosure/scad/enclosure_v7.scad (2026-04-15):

// ============================================================
// Binaural Goggle Controller — Enclosure Rev 3
// Brad Beidler · 2026
// ============================================================
// FIX: cavity subtraction PRESERVES standoff and boss positions
// by subtracting (cavity - standoffs) rather than cavity alone.
// Single monolithic difference — valid manifold, no multi-shell.
//
// PCB STANDOFFS:  (±38, ±27)  h=10mm  PCB drops straight in
// LID BOSSES:     (±43, ±32)  h=30mm  fused to wall corners
// ============================================================

$fn = 48;
RENDER_PART = "body";  // "body" | "lid" | "both"

// ── Core dimensions ──────────────────────────────────────────
INT_W = 92;  INT_L = 72;  INT_H = 30;
WALL  = 3.5;
EXT_W = INT_W + WALL*2;
EXT_L = INT_L + WALL*2;
EXT_H = INT_H + WALL;
OUTER_R = 6.0;  INNER_R = OUTER_R - WALL;

// ── Lid ──────────────────────────────────────────────────────
LID_T = 10.0;  LID_LIP_D = 2.0;  LID_LIP_W = 2.5;  LID_GAP = 0.25;

// ── Inserts ──────────────────────────────────────────────────
INS_D = 3.6;  INS_DEPTH = 7.0;

// ── PCB standoffs ─────────────────────────────────────────────
PCB_OD = 10.0;  PCB_H = 10.0;
PCB_BX = 38.0;  PCB_BY = 27.0;
PCB_BOSSES=[[-PCB_BX,-PCB_BY],[PCB_BX,-PCB_BY],[-PCB_BX,PCB_BY],[PCB_BX,PCB_BY]];

// ── Lid bosses ────────────────────────────────────────────────
LID_OD = 8.0;   LID_BX = 43.0;  LID_BY = 32.0;
LID_BOSSES=[[-LID_BX,-LID_BY],[LID_BX,-LID_BY],[-LID_BX,LID_BY],[LID_BX,LID_BY]];

// ── Panel connectors ─────────────────────────────────────────
GX16_X=-22; GX16_Z=18; GX16_D=16.2; GX16_ND=20.5; GX16_NH=2.5;
TRS_X=24;   TRS_Z=18;  TRS_D=9.5;
DTAB_W=2.2; DTAB_H=1.6;
LED_X=0;    LED_Z=9;   LED_D=5.2;
DC_X=20;    DC_Z=16;   DC_D=8.2;   DC_ND=12.5;  DC_NH=2.0;
SW_X=-18;   SW_Z=18;   SW_D=12.2;

// ── Feet ─────────────────────────────────────────────────────
FOOT_IN=9.0; FOOT_D=3.5; FOOT_CS_D=6.5; FOOT_CS_H=2.0;
FEET=[
  [-(EXT_W/2-FOOT_IN),-(EXT_L/2-FOOT_IN)],
  [ (EXT_W/2-FOOT_IN),-(EXT_L/2-FOOT_IN)],
  [-(EXT_W/2-FOOT_IN), (EXT_L/2-FOOT_IN)],
  [ (EXT_W/2-FOOT_IN), (EXT_L/2-FOOT_IN)],
];

// ── Helpers ──────────────────────────────────────────────────
module rrect(w,l,h,r) {
    r=max(0.1,min(r,min(w,l)/2-0.1));
    hull() for(xi=[-(w/2-r),(w/2-r)]) for(yi=[-(l/2-r),(l/2-r)])
        translate([xi,yi,0]) cylinder(r=r,h=h,$fn=32);
}

module ins_hole() {
    translate([0,0,-0.01]) {
        cylinder(d1=INS_D+0.6, d2=INS_D, h=0.8, $fn=24);
        cylinder(d=INS_D, h=INS_DEPTH+0.01, $fn=24);
    }
}

// ── ENCLOSURE BODY ───────────────────────────────────────────
module enclosure_body() {
    difference() {
        // ── Starting solid ────────────────────────────────────
        rrect(EXT_W, EXT_L, EXT_H, OUTER_R);

        // ── Cavity — with standoffs protected ─────────────────
        // Subtract (cavity MINUS standoff cylinders).
        // The standoff cylinders are removed from the subtraction
        // volume, so those areas are NOT hollowed out → pillars remain.
        difference() {
            // Full interior cavity
            translate([0, 0, WALL])
                rrect(INT_W, INT_L, INT_H + 0.1, INNER_R);
            // Protect PCB standoff positions (cylinder slightly larger/deeper)
            for(p = PCB_BOSSES)
                translate([p[0], p[1], WALL - 0.1])
                    cylinder(d = PCB_OD + 0.1, h = PCB_H + 0.2, $fn = 36);
            // Protect lid boss positions
            for(p = LID_BOSSES)
                translate([p[0], p[1], WALL - 0.1])
                    cylinder(d = LID_OD + 0.1, h = INT_H + 0.2, $fn = 36);
        }

        // ── Insert holes ──────────────────────────────────────
        // Drilled after cavity so they go into the preserved pillars
        for(p = PCB_BOSSES)
            translate([p[0], p[1], WALL + PCB_H])
                mirror([0, 0, 1]) ins_hole();
        for(p = LID_BOSSES)
            translate([p[0], p[1], WALL + INT_H])
                mirror([0, 0, 1]) ins_hole();

        // ── Front panel (+Y face) ─────────────────────────────
        translate([GX16_X, EXT_L/2+0.01, GX16_Z]) rotate([90,0,0]) {
            cylinder(d=GX16_D, h=WALL+0.02, $fn=36);
            translate([0,0,WALL]) cylinder(d=GX16_ND, h=GX16_NH, $fn=36);
        }
        translate([TRS_X, EXT_L/2+0.01, TRS_Z]) rotate([90,0,0]) {
            cylinder(d=TRS_D, h=WALL+0.02, $fn=36);
            translate([0, TRS_D/2+DTAB_H/2-0.01, 0])
                cube([DTAB_W, DTAB_H+0.02, WALL*0.6], center=true);
        }
        translate([LED_X, EXT_L/2+0.01, LED_Z]) rotate([90,0,0])
            cylinder(d=LED_D, h=WALL+0.02, $fn=24);

        // ── Rear panel (−Y face) ──────────────────────────────
        translate([DC_X, -(EXT_L/2)-0.01, DC_Z]) rotate([-90,0,0]) {
            cylinder(d=DC_D, h=WALL+0.02, $fn=32);
            translate([0,0,WALL]) cylinder(d=DC_ND, h=DC_NH, $fn=32);
        }
        translate([SW_X, -(EXT_L/2)-0.01, SW_Z]) rotate([-90,0,0])
            cylinder(d=SW_D, h=WALL+0.02, $fn=36);

        // ── Bottom feet ───────────────────────────────────────
        for(p = FEET) translate([p[0],p[1],-0.01]) {
            cylinder(d=FOOT_CS_D, h=FOOT_CS_H+0.01, $fn=24);
            cylinder(d=FOOT_D,    h=WALL+0.02,       $fn=24);
        }

        // ── Side vents (3 per side) ───────────────────────────
        for(sx=[-1,1]) for(vy=[-22,0,22])
            translate([sx*(EXT_W/2+0.01), vy, EXT_H/2]) rotate([0,90,0])
                hull() for(dz=[-11,11]) translate([dz,0,0])
                    cylinder(d=2.5, h=WALL+0.02, $fn=18);

        // ── Front label (debossed) ────────────────────────────
        translate([0, EXT_L/2-0.55, 5.5]) rotate([90,0,0])
        linear_extrude(0.6)
            text("BINAURAL GOGGLE", size=3.8,
                 font="Liberation Mono:style=Bold",
                 halign="center", valign="center");
    }
}

// ── ENCLOSURE LID ────────────────────────────────────────────
module enclosure_lid() {
    difference() {
        union() {
            rrect(EXT_W, EXT_L, LID_T, OUTER_R);
            difference() {
                rrect(INT_W-LID_GAP*2, INT_L-LID_GAP*2, LID_LIP_D+0.01,
                      max(0.5, INNER_R-LID_GAP));
                translate([0,0,-0.01])
                    rrect(INT_W-LID_GAP*2-LID_LIP_W*2,
                          INT_L-LID_GAP*2-LID_LIP_W*2,
                          LID_LIP_D+0.1,
                          max(0.5, INNER_R-LID_GAP-LID_LIP_W));
            }
        }
        for(p = LID_BOSSES) translate([p[0],p[1],-0.01]) {
            cylinder(d=3.4, h=LID_T+0.02, $fn=24);
            translate([0,0,LID_T-2.2]) cylinder(d1=3.4,d2=6.5, h=2.3, $fn=24);
        }
    }
}

// ── Render ───────────────────────────────────────────────────
if(RENDER_PART=="body") {
    enclosure_body();
} else if(RENDER_PART=="lid") {
    enclosure_lid();
} else {
    color("#3a5a4a",0.85) enclosure_body();
    translate([0,0,EXT_H+10]) color("#4a6a5a",0.75) enclosure_lid();
}

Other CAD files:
hardware/enclosure/stl/enclosure_body_v7.stl

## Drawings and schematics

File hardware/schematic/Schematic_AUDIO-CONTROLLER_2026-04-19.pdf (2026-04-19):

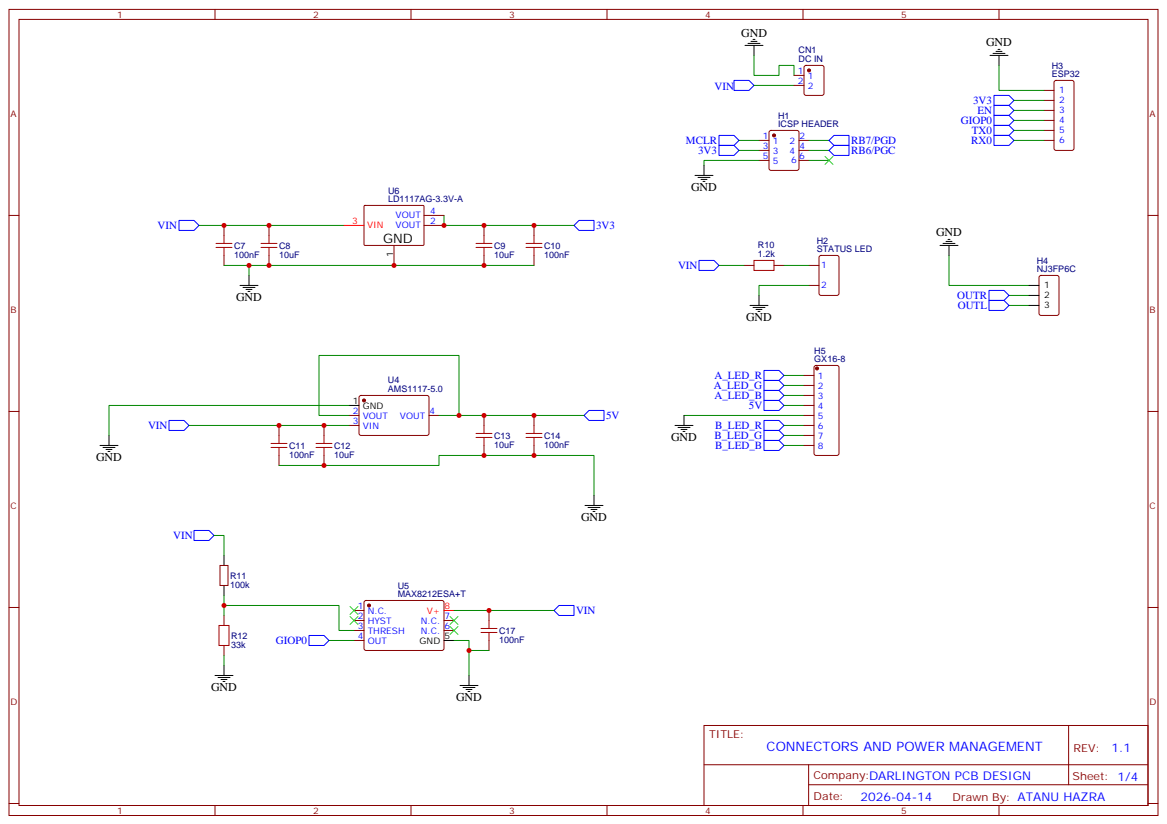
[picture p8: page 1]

Company:DARLINGTON PCB DESIGN

Drawn By: ATANU HAZRA

IO0 27 IO35 28 IO36 29 IO37 30 IO38 31 IO39 32 IO40 33 IO41 34 IO42 35 RXD0 36 TXD0 37 IO2 38 IO1 39 GND 40

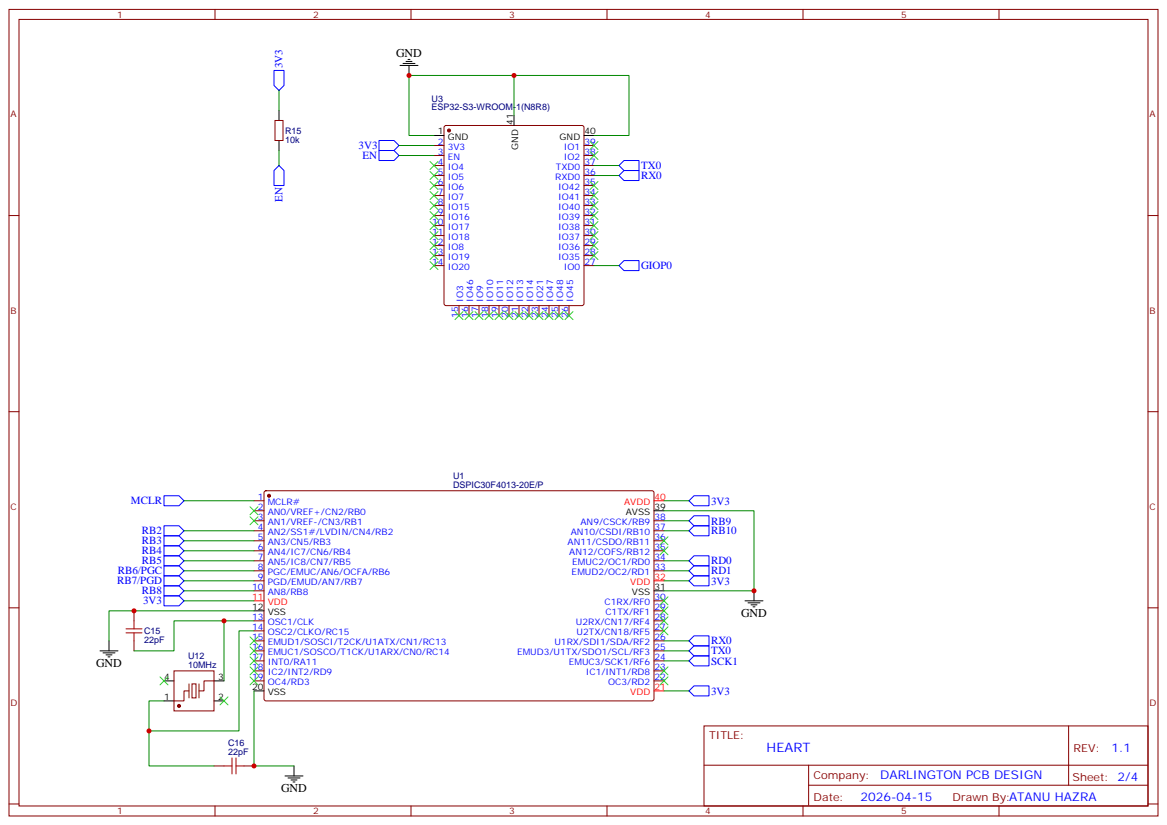
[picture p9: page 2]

Company: DARLINGTON PCB DESIGN

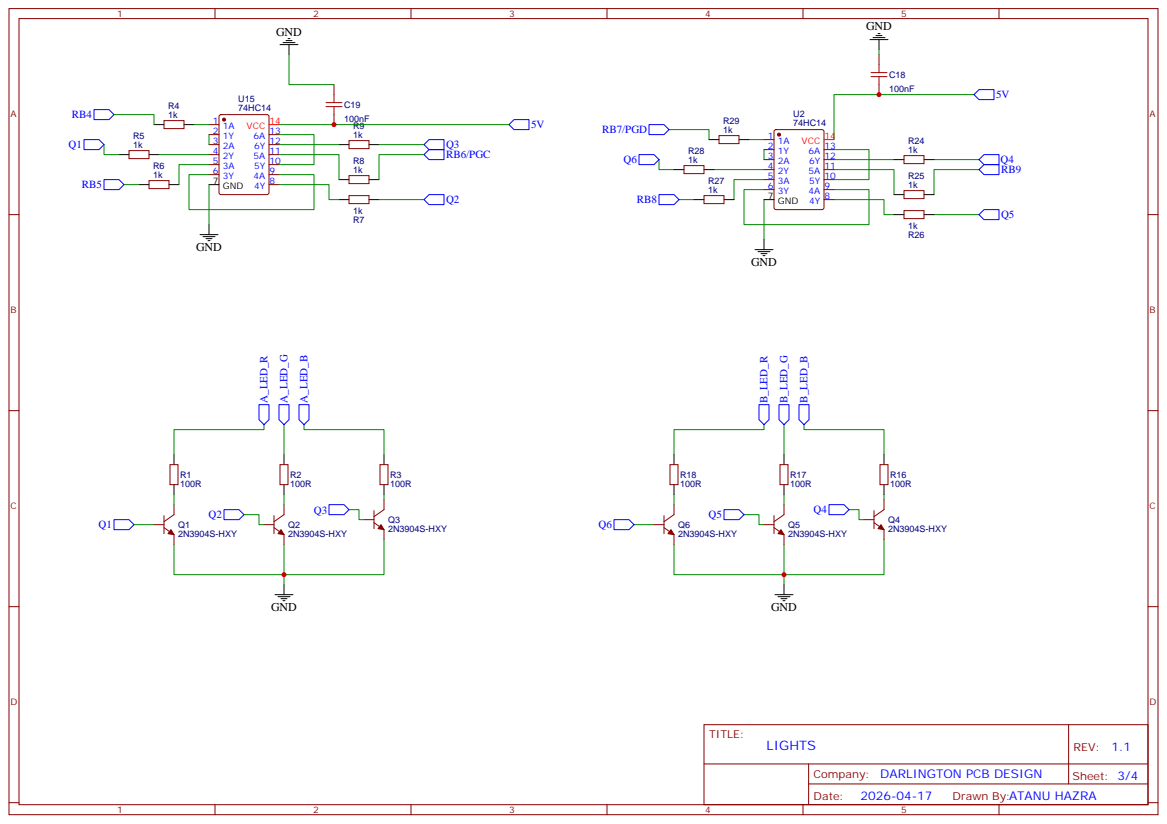
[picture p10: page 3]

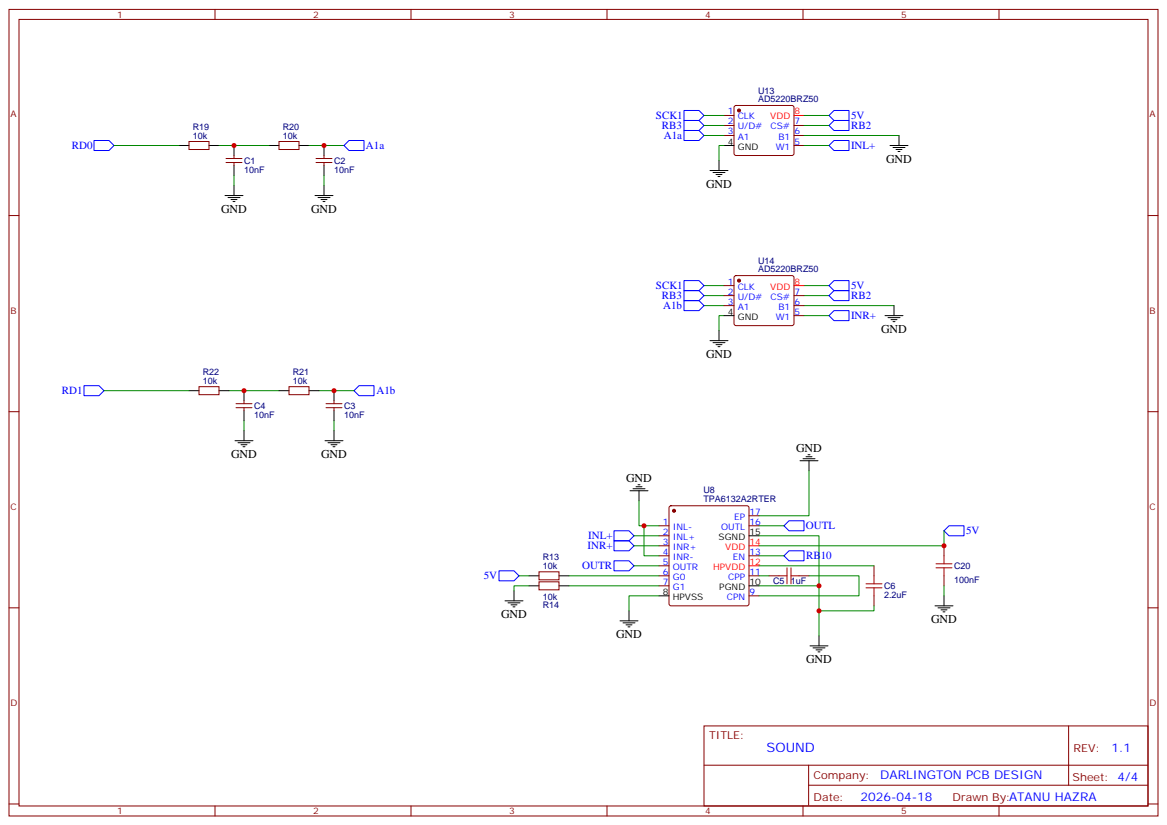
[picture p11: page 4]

TPA6132A2RTER
PGND 10 CPP 11 HPVDD 12 EN 13 VDD 14 SGND 15 OUTL 16 EP 17

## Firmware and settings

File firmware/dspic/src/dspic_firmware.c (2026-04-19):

/*
 * dspic_firmware.c
 * Binaural Beat + RGB LED Goggle Controller
 * Target: dsPIC30F4013-20I/P, 40-pin PDIP, socketed
 * Fcy: 20MHz (10MHz crystal x PLL4)
 *
 * PIN ASSIGNMENTS (final PCB rev 1.1, Atan/Darlington PCB Design):
 *
 *   POWER:
 *     VDD  = pin 11, 21, 32, 40  (+3.3V)
 *     VSS  = pin 12, 20, 31, 39  (GND)
 *     AVDD = pin 40              (+3.3V analog)
 *     AVSS = pin 39              (GND analog)
 *
 *   CLOCK:
 *     OSC1 = pin 13  (10MHz crystal)
 *     OSC2 = pin 14  (10MHz crystal)
 *
 *   AUDIO PWM OUTPUT:
 *     OC1/RD0 = pin 34  (Left channel PWM)
 *     OC2/RD1 = pin 33  (Right channel PWM)
 *
 *   SPI1 -> AD5220 digital pot (volume):
 *     SCK1/RF6 = pin 24  (SPI clock)
 *     SDO1/RF3 = pin 25  (SPI data out -> AD5220 DI)
 *     RB2      = pin 4   (/CS  - chip select, active low)
 *     RB3      = pin 5   (U/D  - up/down direction)
 *
 *   UART2 -> ESP32 Serial2 (GPIO16/17):
 *     U2TX/RF5 = pin 27  (dsPIC TX -> ESP32 RX, GPIO16)
 *     U2RX/RF4 = pin 28  (dsPIC RX -> ESP32 TX, GPIO17)
 *
 *   RGB LED DRIVER (via 74HC14 + 2N3904):
 *     RB4 = pin 6   (Eye A - Red)
 *     RB5 = pin 7   (Eye A - Green)
 *     RB6 = pin 8   (Eye A - Blue)   NOTE: shared with PGC, LEDs flash during ICSP programming
 *     RB7 = pin 9   (Eye B - Red)    NOTE: shared with PGD, LEDs flash during ICSP programming
 *     RB8 = pin 10  (Eye B - Green)
 *     RB9 = pin 38  (Eye B - Blue)
 *
 *   TPA6132A2 HEADPHONE AMP ENABLE:
 *     RB10 = pin 37  (EN pin of TPA6132A2 - must be HIGH to enable amp)
 *
 *   MCLR:
 *     MCLR = pin 1   (10k pullup to 3.3V, ICSP reset)
 *
 * ARCHITECTURE:
 *   - Timer1 ISR @ 8kHz: DDS sine generation (L+R channels), beat sequencer,
 *     soft-PWM for RGB LEDs
 *   - OC1/OC2: PWM output ~256kHz, duty cycle set by DDS
 *   - SPI1: AD5220 volume control (write-only, 64 steps, pulse /CS with U/D set)
 *   - UART2: 9600 baud command parser (from ESP32)
 *
 * BEAT PATTERN (Tomás Cobos / published protocol):
 *   Baseline: 4Hz (theta) continuous
 *   Spikes:   8Hz for 40s every ~8min
 *   Dips:     2Hz for 90s every ~13min
 *   Transitions: 3s linear ramp
 *
 * COMPILE: MPLAB X + XC16
 * PROGRAM: PICkit 4 via ICSP header J1 (MCLR/VDD/VSS/PGD/PGC)
 */

#include <xc.h>
#include <stdint.h>
#include <string.h>

/* ── Configuration bits ──────────────────────────────────────────────── */
_FOSC(CSW_FSCM_OFF & XT_PLL4);   /* 10MHz crystal x PLL4 = 40MHz, Fcy=20MHz */
_FWDT(WDT_OFF);
_FBORPOR(PBOR_OFF & MCLR_EN);
_FGS(CODE_PROT_OFF);

/* ── Fcy and derived constants ───────────────────────────────────────── */
#define FCY         20000000UL
#define FSAMP       8000UL          /* DDS sample rate (Hz) */
#define PWM_PERIOD  78              /* OC period for ~256kHz PWM (FCY/256kHz) */
#define UART_BAUD   9600

/* ── DDS sine table (256 entries, 8-bit, centered at 128) ────────────── */
static const uint8_t sine_table[256] = {
    128,131,134,137,140,143,146,149,152,155,158,161,164,167,170,173,
    176,179,182,184,187,190,192,195,198,200,203,205,208,210,212,215,
    217,219,221,223,225,227,229,231,233,234,236,238,239,240,242,243,
    244,245,246,247,248,249,250,250,251,252,252,253,253,253,254,254,
    254,254,254,254,254,253,253,253,252,252,251,250,250,249,248,247,
    246,245,244,243,242,240,239,238,236,234,233,231,229,227,225,223,
    221,219,217,215,212,210,208,205,203,200,198,195,192,190,187,184,
    182,179,176,173,170,167,164,161,158,155,152,149,146,143,140,137,
    134,131,128,124,121,118,115,112,109,106,103,100, 97, 94, 91, 88,
     85, 82, 79, 77, 74, 71, 69, 66, 63, 61, 58, 56, 53, 51, 49, 46,
     44, 42, 40, 38, 36, 34, 32, 30, 28, 27, 25, 23, 22, 21, 19, 18,
     17, 16, 15, 14, 13, 12, 11, 11, 10,  9,  9,  8,  8,  8,  7,  7,
      7,  7,  7,  7,  7,  8,  8,  8,  9,  9, 10, 11, 11, 12, 13, 14,
     15, 16, 17, 18, 19, 21, 22, 23, 25, 27, 28, 30, 32, 34, 36, 38,
     40, 42, 44, 46, 49, 51, 53, 56, 58, 61, 63, 66, 69, 71, 74, 77,
     79, 82, 85, 88, 91, 94, 97,100,103,106,109,112,115,118,121,124
};

/* ── DDS state ───────────────────────────────────────────────────────── */
static uint32_t phase_acc_L = 0;    /* 32-bit phase accumulator, left  */
static uint32_t phase_acc_R = 0;    /* 32-bit phase accumulator, right */
static uint32_t phase_inc_L = 0;    /* phase increment = freq_L * 2^32 / FSAMP */
static uint32_t phase_inc_R = 0;

/* carrier + beat: L = Fc, R = Fc + beat_freq */
static float carrier_hz   = 200.0f; /* carrier frequency (Hz) */
static float beat_hz      = 4.0f;   /* current beat frequency (Hz) */
static float target_beat  = 4.0f;   /* target beat for ramping */
static float ramp_step    = 0.0f;   /* per-sample ramp increment */

/* Beat sequencer timing (in samples at 8kHz) */
#define SAMPLES_PER_SEC     FSAMP
#define BASELINE_BEAT_HZ    4.0f
#define SPIKE_BEAT_HZ       8.0f
#define DIP_BEAT_HZ         2.0f
#define SPIKE_DURATION      (40UL  * SAMPLES_PER_SEC)
#define DIP_DURATION        (90UL  * SAMPLES_PER_SEC)
#define SPIKE_INTERVAL      (480UL * SAMPLES_PER_SEC)   /* ~8min  */
#define DIP_INTERVAL        (780UL * SAMPLES_PER_SEC)   /* ~13min */
#define RAMP_DURATION       (3UL   * SAMPLES_PER_SEC)

static uint32_t sequencer_tick  = 0;
static uint32_t next_spike      = SPIKE_INTERVAL;
static uint32_t next_dip        = DIP_INTERVAL;
static uint32_t event_end       = 0;
typedef enum { SEQ_BASELINE, SEQ_SPIKE, SEQ_DIP } seq_state_t;
static seq_state_t seq_state = SEQ_BASELINE;

/* ── RGB soft-PWM state ──────────────────────────────────────────────── */
/* 6 channels: [0]=A_R [1]=A_G [2]=A_B [3]=B_R [4]=B_G [5]=B_B */
static uint8_t  rgb_target[6]  = {255, 0, 0, 255, 0, 0}; /* default: red */
static uint8_t  rgb_current[6] = {0};
static uint8_t  pwm_counter    = 0;
static uint16_t led_tick        = 0;
#define LED_FADE_RATE   2   /* fade step per 8kHz tick interval */

/* ── Volume ──────────────────────────────────────────────────────────── */
static uint8_t volume_steps = 32;   /* 0-63, current position */

/* ── UART command buffer ─────────────────────────────────────────────── */
#define CMD_BUF_LEN 32
static char  cmd_buf[CMD_BUF_LEN];
static uint8_t cmd_idx = 0;
static volatile uint8_t cmd_ready = 0;

/* ─────────────────────────────────────────────────────────────────────
   UTILITY: compute DDS phase increment
   phase_inc = freq * 2^32 / FSAMP
   ───────────────────────────────────────────────────────────────────── */
static uint32_t freq_to_inc(float hz) {
    return (uint32_t)(hz * (4294967296.0f / (float)FSAMP));
}

/* ─────────────────────────────────────────────────────────────────────
   SPI1 / AD5220 volume control
   AD5220 is write-only (no MISO). To step wiper:
     1. Set U/D pin (RB3) for direction
     2. Assert /CS low (RB2)
     3. Pulse CLK (handled by SPI peripheral or bit-bang)
     4. Deassert /CS high
   We use a simple bit-bang approach for reliability.
   ───────────────────────────────────────────────────────────────────── */
#define AD5220_CS_LOW()   LATBbits.LATB2 = 0
#define AD5220_CS_HIGH()  LATBbits.LATB2 = 1
#define AD5220_UD_UP()    LATBbits.LATB3 = 1
#define AD5220_UD_DOWN()  LATBbits.LATB3 = 0
#define AD5220_CLK_LOW()  LATFbits.LATF6 = 0
#define AD5220_CLK_HIGH() LATFbits.LATF6 = 1

static void ad5220_step(uint8_t up) {
    if (up) AD5220_UD_UP(); else AD5220_UD_DOWN();
    AD5220_CS_LOW();
    __asm__("nop"); __asm__("nop");
    AD5220_CLK_HIGH();
    __asm__("nop"); __asm__("nop");
    AD5220_CLK_LOW();
    __asm__("nop"); __asm__("nop");
    AD5220_CS_HIGH();
}

/* Set absolute volume (0-63). AD5220 has no read-back so we track position. */
static void ad5220_set_volume(uint8_t target) {
    if (target > 63) target = 63;
    while (volume_steps < target) { ad5220_step(1); volume_steps++; }
    while (volume_steps > target) { ad5220_step(0); volume_steps--; }
}

/* ─────────────────────────────────────────────────────────────────────
   RGB LED output (soft-PWM via PORTB)
   Channels mapped to PORTB bits:
     RB4 = A_Red, RB5 = A_Green, RB6 = A_Blue
     RB7 = B_Red, RB8 = B_Green, RB9 = B_Blue
   ───────────────────────────────────────────────────────────────────── */
static void rgb_update_outputs(void) {
    /* soft-PWM: compare pwm_counter against each channel's current value */
    LATBbits.LATB4 = (pwm_counter < rgb_current[0]) ? 1 : 0; /* A_R */
    LATBbits.LATB5 = (pwm_counter < rgb_current[1]) ? 1 : 0; /* A_G */
    LATBbits.LATB6 = (pwm_counter < rgb_current[2]) ? 1 : 0; /* A_B */
    LATBbits.LATB7 = (pwm_counter < rgb_current[3]) ? 1 : 0; /* B_R */
    LATBbits.LATB8 = (pwm_counter < rgb_current[4]) ? 1 : 0; /* B_G */
    LATBbits.LATB9 = (pwm_counter < rgb_current[5]) ? 1 : 0; /* B_B */
    pwm_counter++;
}

/* Fade current RGB values toward targets */
static void rgb_fade_step(void) {
    uint8_t i;
    for (i = 0; i < 6; i++) {
        if (rgb_current[i] < rgb_target[i]) {
            uint8_t delta = rgb_target[i] - rgb_current[i];
            rgb_current[i] += (delta > LED_FADE_RATE) ? LED_FADE_RATE : delta;
        } else if (rgb_current[i] > rgb_target[i]) {
            uint8_t delta = rgb_current[i] - rgb_target[i];
            rgb_current[i] -= (delta > LED_FADE_RATE) ? LED_FADE_RATE : delta;
        }
    }
}

/* ─────────────────────────────────────────────────────────────────────
   Beat sequencer — called every sample from Timer1 ISR
   ───────────────────────────────────────────────────────────────────── */
static void sequencer_tick_fn(void) {
    sequencer_tick++;

    /* ramp beat_hz toward target_beat */
    if (beat_hz < target_beat) {
        beat_hz += ramp_step;
        if (beat_hz > target_beat) beat_hz = target_beat;
    } else if (beat_hz > target_beat) {
        beat_hz -= ramp_step;
        if (beat_hz < target_beat) beat_hz = target_beat;
    }

    /* update phase increments whenever beat changes */
    phase_inc_L = freq_to_inc(carrier_hz);
    phase_inc_R = freq_to_inc(carrier_hz + beat_hz);

    /* state machine */
    switch (seq_state) {
        case SEQ_BASELINE:
            if (sequencer_tick >= next_spike) {
                target_beat = SPIKE_BEAT_HZ;
                ramp_step = (SPIKE_BEAT_HZ - beat_hz) / (float)RAMP_DURATION;
                if (ramp_step < 0) ramp_step = -ramp_step;
                event_end = sequencer_tick + SPIKE_DURATION;
                next_spike = sequencer_tick + SPIKE_INTERVAL;
                seq_state = SEQ_SPIKE;
            } else if (sequencer_tick >= next_dip) {
                target_beat = DIP_BEAT_HZ;
                ramp_step = (beat_hz - DIP_BEAT_HZ) / (float)RAMP_DURATION;
                if (ramp_step < 0) ramp_step = -ramp_step;
                event_end = sequencer_tick + DIP_DURATION;
                next_dip = sequencer_tick + DIP_INTERVAL;
                seq_state = SEQ_DIP;
            }
            break;

        case SEQ_SPIKE:
        case SEQ_DIP:
            if (sequencer_tick >= event_end) {
                target_beat = BASELINE_BEAT_HZ;
                ramp_step = 0.0006f; /* ~3s ramp back at 8kHz */
                seq_state = SEQ_BASELINE;
            }
            break;
    }
}

/* ─────────────────────────────────────────────────────────────────────
   Timer1 ISR — 8kHz sample rate
   Generates DDS samples, updates PWM duty cycles, drives LED soft-PWM
   ───────────────────────────────────────────────────────────────────── */
void __attribute__((__interrupt__, no_auto_psv)) _T1Interrupt(void) {
    /* DDS: advance phase accumulators */
    phase_acc_L += phase_inc_L;
    phase_acc_R += phase_inc_R;

    /* Read sine table (top 8 bits of 32-bit accumulator = table index) */
    uint8_t samp_L = sine_table[phase_acc_L >> 24];
    uint8_t samp_R = sine_table[phase_acc_R >> 24];

    /* Update OC1/OC2 duty cycle (PWM output) */
    OC1RS = (uint16_t)samp_L * PWM_PERIOD / 255;
    OC2RS = (uint16_t)samp_R * PWM_PERIOD / 255;

    /* LED soft-PWM (run every sample for ~31kHz PWM rate) */
    rgb_update_outputs();

    /* LED fade (run at ~31Hz: every 256 samples) */
    led_tick++;
    if (led_tick >= 256) {
        led_tick = 0;
        rgb_fade_step();
    }

    /* Beat sequencer */
    sequencer_tick_fn();

    IFS0bits.T1IF = 0; /* clear interrupt flag */
}

/* ─────────────────────────────────────────────────────────────────────
   UART2 RX ISR — collect command bytes into buffer
   Commands are newline-terminated ASCII strings from ESP32
   ───────────────────────────────────────────────────────────────────── */
void __attribute__((__interrupt__, no_auto_psv)) _U2RXInterrupt(void) {
    char c = U2RXREG;
    IFS1bits.U2RXIF = 0;

    if (c == '\n' || c == '\r') {
        if (cmd_idx > 0) {
            cmd_buf[cmd_idx] = '\0';
            cmd_ready = 1;
            cmd_idx = 0;
        }
    } else if (cmd_idx < CMD_BUF_LEN - 1) {
        cmd_buf[cmd_idx++] = c;
    }
}

/* ─────────────────────────────────────────────────────────────────────
   UART2 transmit helper
   ───────────────────────────────────────────────────────────────────── */
static void uart2_putch(char c) {
    while (!U2STAbits.TRMT);
    U2TXREG = c;
}

static void uart2_puts(const char *s) {
    while (*s) uart2_putch(*s++);
    uart2_putch('\n');
}

/* ─────────────────────────────────────────────────────────────────────
   Command parser
   Protocol (from ESP32):
     BEAT:<hz>        set beat frequency (e.g. BEAT:4.0)
     CARRIER:<hz>     set carrier frequency (e.g. CARRIER:200.0)
     VOL:<0-63>       set volume step
     RGB_A:<r>,<g>,<b>  set eye A color (0-255 each)
     RGB_B:<r>,<g>,<b>  set eye B color
     RGB_AB:<r>,<g>,<b> set both eyes same color
     STATUS           reply with current state
     RESET            reset sequencer to baseline
   ───────────────────────────────────────────────────────────────────── */
static void process_command(char *cmd) {
    if (strncmp(cmd, "BEAT:", 5) == 0) {
        float hz = 0;
        /* simple float parse */
        char *p = cmd + 5;
        float whole = 0, frac = 0, fdiv = 1;
        uint8_t in_frac = 0;
        while (*p) {
            if (*p == '.') { in_frac = 1; }
            else if (*p >= '0' && *p <= '9') {
                if (in_frac) { frac = frac * 10 + (*p - '0'); fdiv *= 10; }
                else whole = whole * 10 + (*p - '0');
            }
            p++;
        }
        hz = whole + frac / fdiv;
        if (hz > 0.5f && hz <= 40.0f) {
            target_beat = hz;
            ramp_step = 0.0006f;
        }
        uart2_puts("OK:BEAT");

    } else if (strncmp(cmd, "CARRIER:", 8) == 0) {
        /* same float parse as above */
        char *p = cmd + 8;
        float whole = 0, frac = 0, fdiv = 1;
        uint8_t in_frac = 0;
        while (*p) {
            if (*p == '.') { in_frac = 1; }
            else if (*p >= '0' && *p <= '9') {
                if (in_frac) { frac = frac * 10 + (*p - '0'); fdiv *= 10; }
                else whole = whole * 10 + (*p - '0');
            }
            p++;
        }
        float hz = whole + frac / fdiv;
        if (hz >= 50.0f && hz <= 1500.0f) carrier_hz = hz;
        uart2_puts("OK:CARRIER");

    } else if (strncmp(cmd, "VOL:", 4) == 0) {
        uint8_t v = (uint8_t)atoi(cmd + 4);
        if (v > 63) v = 63;
        ad5220_set_volume(v);
        uart2_puts("OK:VOL");

    } else if (strncmp(cmd, "RGB_A:", 6) == 0) {
        uint8_t r = 0, g = 0, b = 0;
        sscanf(cmd + 6, "%hhu,%hhu,%hhu", &r, &g, &b);
        rgb_target[0] = r; rgb_target[1] = g; rgb_target[2] = b;
        uart2_puts("OK:RGB_A");

    } else if (strncmp(cmd, "RGB_B:", 6) == 0) {
        uint8_t r = 0, g = 0, b = 0;
        sscanf(cmd + 6, "%hhu,%hhu,%hhu", &r, &g, &b);
        rgb_target[3] = r; rgb_target[4] = g; rgb_target[5] = b;
        uart2_puts("OK:RGB_B");

    } else if (strncmp(cmd, "RGB_AB:", 7) == 0) {
        uint8_t r = 0, g = 0, b = 0;
        sscanf(cmd + 7, "%hhu,%hhu,%hhu", &r, &g, &b);
        rgb_target[0] = r; rgb_target[1] = g; rgb_target[2] = b;
        rgb_target[3] = r; rgb_target[4] = g; rgb_target[5] = b;
        uart2_puts("OK:RGB_AB");

    } else if (strcmp(cmd, "STATUS") == 0) {
        char buf[64];
        /* send beat freq as integer*10 to avoid float formatting */
        uint16_t beat_x10 = (uint16_t)(beat_hz * 10.0f);
        uint16_t carr_x10 = (uint16_t)(carrier_hz * 10.0f);
        sprintf(buf, "BEAT:%u.%u CARRIER:%u.%u VOL:%u",
            beat_x10 / 10, beat_x10 % 10,
            carr_x10 / 10, carr_x10 % 10,
            volume_steps);
        uart2_puts(buf);

    } else if (strcmp(cmd, "RESET") == 0) {
        target_beat = BASELINE_BEAT_HZ;
        ramp_step = 0.0006f;
        seq_state = SEQ_BASELINE;
        sequencer_tick = 0;
        next_spike = SPIKE_INTERVAL;
        next_dip = DIP_INTERVAL;
        uart2_puts("OK:RESET");

    } else {
        uart2_puts("ERR:UNKNOWN");
    }
}

/* ─────────────────────────────────────────────────────────────────────
   Hardware init
   ───────────────────────────────────────────────────────────────────── */
static void init_gpio(void) {
    /* Set PORTB pins as digital outputs:
       RB2 (/CS), RB3 (U/D), RB4-RB9 (RGB LEDs), RB10 (TPA6132A2 EN) */
    ADPCFG = 0xFFFF;                /* all ANx pins as digital */
    TRISBbits.TRISB2  = 0;         /* /CS  out */
    TRISBbits.TRISB3  = 0;         /* U/D  out */
    TRISBbits.TRISB4  = 0;         /* A_R  out */
    TRISBbits.TRISB5  = 0;         /* A_G  out */
    TRISBbits.TRISB6  = 0;         /* A_B  out */
    TRISBbits.TRISB7  = 0;         /* B_R  out */
    TRISBbits.TRISB8  = 0;         /* B_G  out */
    TRISBbits.TRISB9  = 0;         /* B_B  out */
    TRISBbits.TRISB10 = 0;         /* TPA EN out */

    /* PORTF: RF3=SDO1 out, RF4=RX2 in, RF5=TX2 out, RF6=SCK1 out */
    TRISFbits.TRISF3 = 0;          /* SDO1 out */
    TRISFbits.TRISF4 = 1;          /* U2RX in  */
    TRISFbits.TRISF5 = 0;          /* U2TX out */
    TRISFbits.TRISF6 = 0;          /* SCK1 out */

    /* PORTD: RD0=OC1 out, RD1=OC2 out */
    TRISDbits.TRISD0 = 0;
    TRISDbits.TRISD1 = 0;

    /* Initial states */
    LATBbits.LATB2  = 1;           /* /CS deasserted */
    LATBbits.LATB3  = 1;           /* U/D default up */
    LATBbits.LATB10 = 1;           /* TPA6132A2 EN HIGH — amp enabled */
    LATB &= ~0x03F0;               /* LEDs off (RB4-RB9 = 0) */
    LATFbits.LATF6  = 0;           /* SCK idle low */
}

static void init_pwm(void) {
    /* OC1 and OC2: PWM mode, period ~256kHz */
    OC1CON = 0x0006;               /* PWM mode, no fault */
    OC2CON = 0x0006;
    OC1R  = 0;                     /* initial duty = 0 */
    OC1RS = 0;
    OC2R  = 0;
    OC2RS = 0;
    /* Timer2 as PWM timebase */
    T2CONbits.TCKPS = 0b00;        /* 1:1 prescaler */
    PR2 = PWM_PERIOD;              /* period register */
    T2CONbits.TON = 1;
    OC1CONbits.OCM = 0b110;        /* PWM mode, fault disabled */
    OC2CONbits.OCM = 0b110;
}

static void init_timer1(void) {
    /* Timer1: 8kHz ISR for DDS */
    T1CON = 0;
    T1CONbits.TCKPS = 0b00;        /* 1:1 prescaler */
    PR1 = (uint16_t)(FCY / FSAMP - 1);  /* = 2499 for 8kHz at 20MHz */
    IPC0bits.T1IP = 6;             /* priority 6 */
    IFS0bits.T1IF = 0;
    IEC0bits.T1IE = 1;
    T1CONbits.TON = 1;
}

static void init_uart2(void) {
    /* UART2 at 9600 baud for ESP32 communication */
    U2BRG  = (uint16_t)(FCY / (16UL * UART_BAUD) - 1);  /* = 129 */
    U2MODE = 0x8000;               /* UART2 enabled, 8N1 */
    U2STA  = 0x0400;               /* TX enabled */
    IFS1bits.U2RXIF = 0;
    IEC1bits.U2RXIE = 1;           /* enable RX interrupt */
}

/* ─────────────────────────────────────────────────────────────────────
   main
   ───────────────────────────────────────────────────────────────────── */
int main(void) {
    /* Initial phase increments: 200Hz carrier, 4Hz beat */
    phase_inc_L = freq_to_inc(carrier_hz);
    phase_inc_R = freq_to_inc(carrier_hz + beat_hz);

    init_gpio();
    init_pwm();
    init_uart2();
    init_timer1();      /* start last — ISR will begin firing */

    /* Set initial volume to mid-range (step 32 of 63) */
    /* AD5220 resets to end-stop on power-up, step up to 32 */
    ad5220_set_volume(32);

    /* Send boot message to ESP32 */
    uart2_puts("READY:BINAURAL_GOGGLE_V2");

    /* Main loop: process UART commands */
    while (1) {
        if (cmd_ready) {
            cmd_ready = 0;
            process_command(cmd_buf);
        }
        /* IDLE — all real work happens in Timer1 ISR */
        Idle();
    }

    return 0;
}

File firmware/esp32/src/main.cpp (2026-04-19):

/*
 * main.cpp — ESP32 Firmware for Binaural Beat Goggle Controller
 * Binaural Goggle Project — github.com/kaisersuzuki/binaural-goggle
 *
 * Hardware: ESP32-WROOM-32E (SMD, JLCPCB assembled)
 * PCB: Darlington PCB Design rev 1.1
 *
 * PIN ASSIGNMENTS:
 *   GPIO16 (RX2) — Serial2 RX from dsPIC U2TX (RF5)
 *   GPIO17 (TX2) — Serial2 TX to   dsPIC U2RX (RF4)
 *   GPIO0        — Boot mode / used on PCB for voltage divider (do not use as output)
 *
 * FEATURES:
 *   - WiFi AP mode: SSID "BinauralGoggle" / "meditate123"
 *   - Web UI at 192.168.4.1 (sliders: beat freq, carrier freq, volume, RGB)
 *   - OTA firmware update via ArduinoOTA
 *   - Serial2 command protocol to dsPIC (9600 baud)
 *   - STA fallback: if STA_SSID defined, tries STA first, falls back to AP
 *
 * COMMAND PROTOCOL TO dsPIC:
 *   BEAT:<hz>           set beat frequency
 *   CARRIER:<hz>        set carrier frequency
 *   VOL:<0-63>          set volume step
 *   RGB_A:<r>,<g>,<b>   set eye A color
 *   RGB_B:<r>,<g>,<b>   set eye B color
 *   RGB_AB:<r>,<g>,<b>  set both eyes
 *   STATUS              request status string
 *   RESET               reset sequencer
 *
 * BUILD: VS Code + PlatformIO, ESP32 Arduino framework
 * FLASH: Via J2 header (GND/3V3/EN/IO0/TX0/RX0) with FTDI/CP2102 adapter
 *        OR via OTA after first flash
 */

#include <Arduino.h>
#include <WiFi.h>
#include <WebServer.h>
#include <ArduinoOTA.h>

/* ── WiFi credentials ────────────────────────────────────────────────── */
#define AP_SSID     "BinauralGoggle"
#define AP_PASS     "meditate123"
#define AP_IP       "192.168.4.1"

/* Uncomment to enable STA fallback (connect to home network first) */
// #define STA_SSID "your_home_ssid"
// #define STA_PASS "your_home_password"

/* ── Serial2 to dsPIC ────────────────────────────────────────────────── */
#define DSPIC_RX_PIN  16    /* GPIO16 = Serial2 RX (from dsPIC TX RF5) */
#define DSPIC_TX_PIN  17    /* GPIO17 = Serial2 TX (to   dsPIC RX RF4) */
#define DSPIC_BAUD    9600

/* ── State ───────────────────────────────────────────────────────────── */
static float  g_beat_hz    = 4.0f;
static float  g_carrier_hz = 200.0f;
static uint8_t g_volume    = 32;
static uint8_t g_rgb_a[3]  = {255, 0, 0};  /* Eye A: red */
static uint8_t g_rgb_b[3]  = {255, 0, 0};  /* Eye B: red */
static String  g_dspic_status = "unknown";
static bool    g_dspic_ready  = false;

WebServer server(80);

/* ─────────────────────────────────────────────────────────────────────
   Send command to dsPIC via Serial2
   ───────────────────────────────────────────────────────────────────── */
static void dspic_send(const String &cmd) {
    Serial2.println(cmd);
    Serial.println("[->dsPIC] " + cmd);
}

/* ─────────────────────────────────────────────────────────────────────
   Web UI HTML
   Single-page app with sliders and color pickers
   ───────────────────────────────────────────────────────────────────── */
static const char WEB_UI[] PROGMEM = R"rawliteral(
<!DOCTYPE html>
<html lang="en">
<head>
<meta charset="UTF-8">
<meta name="viewport" content="width=device-width, initial-scale=1.0">
<title>Binaural Goggle</title>
<style>
  * { box-sizing: border-box; margin: 0; padding: 0; }
  body {
    background: #0d1117;
    color: #c9d1d9;
    font-family: 'Courier New', monospace;
    padding: 20px;
    max-width: 480px;
    margin: 0 auto;
  }
  h1 { color: #7ab87a; font-size: 14px; letter-spacing: 3px;
       text-transform: uppercase; margin-bottom: 4px; }
  .subtitle { color: #3d5a3d; font-size: 10px; margin-bottom: 24px; }
  .card {
    background: #161b22;
    border: 1px solid #21262d;
    border-radius: 4px;
    padding: 16px;
    margin-bottom: 12px;
  }
  .card h2 { font-size: 10px; color: #7ab87a; letter-spacing: 2px;
             text-transform: uppercase; margin-bottom: 12px; }
  label { font-size: 11px; color: #8b949e; display: flex;
          justify-content: space-between; margin-bottom: 6px; }
  input[type=range] {
    width: 100%; height: 4px; margin-bottom: 14px;
    accent-color: #7ab87a;
  }
  .color-row { display: flex; gap: 12px; align-items: center; }
  input[type=color] { width: 48px; height: 36px; border: none;
                      background: none; cursor: pointer; border-radius: 4px; }
  .btn {
    background: #1e3a1e;
    border: 1px solid #3d7a3d;
    color: #7ab87a;
    padding: 10px 20px;
    font-family: 'Courier New', monospace;
    font-size: 11px;
    letter-spacing: 1px;
    cursor: pointer;
    border-radius: 2px;
    width: 100%;
    text-transform: uppercase;
  }
  .btn:hover { background: #2a4a2a; }
  .btn.danger { border-color: #7a3d3d; color: #c07070; background: #2a1e1e; }
  .status { font-size: 10px; color: #3d5a3d; padding: 8px;
            background: #0d1117; border-radius: 2px; margin-top: 8px;
            min-height: 32px; word-break: break-all; }
  .preset-row { display: flex; gap: 8px; }
  .preset-row .btn { font-size: 9px; padding: 8px; }
</style>
</head>
<body>
<h1>Binaural Goggle</h1>
<div class="subtitle">192.168.4.1 &nbsp;·&nbsp; dsPIC30F4013 + ESP32</div>

<div class="card">
  <h2>Beat Frequency</h2>
  <label>Beat <span id="beat_val">4.0</span> Hz</label>
  <input type="range" id="beat" min="0.5" max="40" step="0.5" value="4.0"
    oninput="document.getElementById('beat_val').textContent=parseFloat(this.value).toFixed(1)">

  <label>Carrier <span id="carrier_val">200</span> Hz</label>
  <input type="range" id="carrier" min="50" max="500" step="5" value="200"
    oninput="document.getElementById('carrier_val').textContent=this.value">

  <div class="preset-row">
    <button class="btn" onclick="setPreset(2,'Delta (2Hz)')">2Hz Delta</button>
    <button class="btn" onclick="setPreset(4,'Theta (4Hz)')">4Hz Theta</button>
    <button class="btn" onclick="setPreset(8,'Alpha (8Hz)')">8Hz Alpha</button>
    <button class="btn" onclick="setPreset(10,'Alpha (10Hz)')">10Hz Alpha</button>
  </div>
</div>

<div class="card">
  <h2>Volume</h2>
  <label>Level <span id="vol_val">32</span> / 63</label>
  <input type="range" id="volume" min="0" max="63" step="1" value="32"
    oninput="document.getElementById('vol_val').textContent=this.value">
</div>

<div class="card">
  <h2>LED Color</h2>
  <label>Eye A</label>
  <div class="color-row">
    <input type="color" id="color_a" value="#ff0000" oninput="previewColor('a',this.value)">
    <span style="font-size:10px;color:#556655">R:<span id="a_r">255</span>
    G:<span id="a_g">0</span> B:<span id="a_b">0</span></span>
  </div>
  <br>
  <label>Eye B</label>
  <div class="color-row">
    <input type="color" id="color_b" value="#ff0000" oninput="previewColor('b',this.value)">
    <span style="font-size:10px;color:#556655">R:<span id="b_r">255</span>
    G:<span id="b_g">0</span> B:<span id="b_b">0</span></span>
  </div>
  <br>
  <button class="btn" onclick="syncColors()">Sync A = B</button>
</div>
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

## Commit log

2026-04-15 Initial commit: hardware, firmware, docs (v7 enclosure, schematic rev 0.2)
    [enclosure_body_v7.stl, enclosure_lid_v7.stl]
2026-04-15 Add enclosure v7 SCAD source; fix dsPIC refs to socketed DIP (not hand-soldered)
    [enclosure_v7.scad]
2026-04-16 Enclosure v8: vertical vents, matched corner radii, holes at Z=24, JLC3DP compliant
    [enclosure_body_v8_FINAL.stl, enclosure_lid_v8_FINAL.stl]
2026-04-19 PCB rev 1.1 final: updated firmware, schematic, PCB layout, docs
    [Autorouter_PCB_AUDIO-CONTROLLER_2_2026-04-19.dsn, BOM_AUDIO-CONTROLLER_2026-04-19.csv, PickAndPlace_PCB_AUDIO-CONTROLLER_2_2026-04-19.csv]
